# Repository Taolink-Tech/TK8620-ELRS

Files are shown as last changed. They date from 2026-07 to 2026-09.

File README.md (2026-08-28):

# TK8620 ELRS

TK8620 ELRS is an ExpressLRS 3.6.4 firmware port and hardware reference package
for TK8620-based TX and RX modules.

This repository is for people who want to use TK8620 hardware quickly and for
developers who want to evaluate, customize, or integrate TK8620-based radio
modules into their own products.

You can use this repository to:

- buy a TK8620 ELRS module and build firmware for it
- review public hardware design files such as schematics, PCB files, BOMs, and
  manufacturing outputs
- modify the hardware reference design for your own product
- use the ELRS firmware port as a compatibility reference for TK8620 hardware

## Purchase and Contact

- Buy TK8620 ELRS TX/RX modules: [Taobao product page](https://item.taobao.com/item.htm?id=1068476636220)
- Company contact: [+8616621375462](tel:+8616621375462)

## Start Here

| Goal | Start with |
| --- | --- |
| Buy a TK8620 ELRS module | [Taobao product page](https://item.taobao.com/item.htm?id=1068476636220) |
| Choose a module and review purchase notes | [`hardware/PURCHASE.md`](hardware/PURCHASE.md) |
| Build TX/RX firmware | [Build](#build) |
| Interpret the status LED or reset a module | [Status LED and Reset](#status-led-and-reset) |
| Check CRSF, SBUS, and AirPort interfaces | [Serial Interfaces](#serial-interfaces) |
| Bind a TX/RX pair | [Binding](#binding) |
| Switch between RC and AirPort | [RC/AirPort Mode](#rcairport-mode) |
| Flash a TX module | [Flash TX](#flash-tx) |
| Flash an RX module over UART | [Flash RX](#flash-rx) |
| Stage RX firmware for wireless update | [Stage RX Firmware For Wireless Update](#stage-rx-firmware-for-wireless-update) |
| Review hardware files | [`hardware/README.md`](hardware/README.md) |
| Customize your own hardware product | [`hardware/CUSTOMIZATION.md`](hardware/CUSTOMIZATION.md) |

## Supported Hardware

| Hardware | Role | Status | Hardware files | Purchase |
| --- | --- | --- | --- | --- |
| TKB-310 TK8620 ELRS TX Module | TX | Released | [`hardware/boards/tk8620-elrs-tx/`](hardware/boards/tk8620-elrs-tx/) | [`hardware/PURCHASE.md`](hardware/PURCHASE.md) |
| TKM-300 TK8620 ELRS RX Module | RX | Released | [`hardware/boards/tk8620-elrs-rx/`](hardware/boards/tk8620-elrs-rx/) | [`hardware/PURCHASE.md`](hardware/PURCHASE.md) |

Use files from the matching module directory. Do not mix TX and RX schematics,
PCB files, BOMs, placement files, or manufacturing outputs.

## Status LED and Reset

### Status LED

| Module | LED pattern | Meaning |
| --- | --- | --- |
| TX | Steady on | Powered and operating normally. This does not by itself confirm that the RX link is connected. |
| TX | One brief flicker | The short binding transmission window is active. This does not confirm that binding succeeded. |
| RX | Steady on | Connected to the TX module. |
| RX | 500 ms on, 500 ms off | Disconnected and waiting for the TX link. |
| RX | Two short flashes, then a pause | Binding mode. |

The RX patterns apply in both RC and AirPort modes. LED color may vary with the
module hardware revision; use the blink pattern rather than color to identify
the state.

### Reset

`configure.cmd` and `burn.cmd` reset the TX module automatically. When either
tool prompts for an RX manual reset, keep the UART grounds connected, briefly
touch the USB-UART adapter's 3.3 V output to the bottom-side `TP5` reset test
point, and release it immediately. See the module-specific reset notes for the
[`TX`](hardware/boards/tk8620-elrs-tx/README.md#reset) and
[`RX`](hardware/boards/tk8620-elrs-rx/README.md#reset) hardware.

## Serial Interfaces

| Mode and module | Interface | Direction | Serial settings |
| --- | --- | --- | --- |
| RC - TKB-310 TX | CRSF handset | Radio to TX, with telemetry return | Half duplex, 8N1; `400000` default, `420000`, or `921600` baud |
| RC - TKM-300 RX | CRSF | Bidirectional RX/flight-controller UART | Full duplex, normal polarity, 8N1, `420000` baud |
| RC - TKM-300 RX | SBUS | RX to flight controller on the `TX/SBUS` pin | Output only, non-inverted, 8E2, `100000` baud |
| AirPort - TX and RX | Transparent UART | Bidirectional TX/RX byte stream | Full duplex, normal polarity, 8N1; baud selected with `configure.cmd` |

The standard unified TX firmware uses CRSF handset input; SBUS handset input is
not enabled. In RC mode, select CRSF or SBUS for the RX from the receiver Lua
`Serial Protocol` setting. AirPort mode uses the TX and RX UART pins for
transparent serial data instead of RC serial protocols.

## Binding

Set both modules to RC mode. Open the transmitter ELRS Lua menu and select
`Bind`. If the RX is not already in binding mode, power it on three times in
quick succession and leave it powered after the third start. Binding is
complete when the RX status LED becomes steady.

## Repository Contents

- `applications/ELRS_Tx/`: TX application firmware source.
- `applications/ELRS_Rx/`: RX application firmware source.
- `applications/ELRS_Common/`: shared TX/RX application source.
- `hardware/`: hardware reference files, purchase notes, manufacturing outputs,
  and customization guidance.
- `open-sdk/include/`: public TK8620 SDK headers.
- `open-sdk/lib/libtk86xx.a`: TK8620 binary SDK library.
- `firmware/bootloader/`: bootloader image used by `burn.cmd`.
- `tools/`: build, flashing, and packaging tools.
- `VERSION`: repository release version.

This repository does not include prebuilt, linked TX or RX application
firmware. The TX and RX firmware images described below are generated locally
when the user runs the build scripts.

## License Model

This is a mixed-license repository. The ELRS application firmware is derived
from ExpressLRS and remains under GPL-3.0. The TK8620 SDK headers and binary
library are provided under the custom
`LicenseRef-Taolink-TK8620-SDK-Package` license in `LICENSE.sdk.md`.

Hardware reference files under `hardware/` are licensed under the permissive
`CERN-OHL-P-2.0` hardware license unless a specific file states another license.
Customers can modify the hardware for their own products without being required
to publish those hardware changes. Scope and trademark notes are in
[`hardware/LICENSE.md`](hardware/LICENSE.md).

Taolink-owned build, flashing, and packaging tools are provided under the
custom `LicenseRef-Taolink-TK8620-Bundled-Tools` license in `LICENSE.tools.md`.
Third-party components retain their upstream licenses as listed in
`THIRD_PARTY_LICENSES.md`.

The TK8620 bootloader binary is provided under the custom
`LicenseRef-Taolink-TK8620-Bootloader-Binary` license in
`LICENSE.bootloader.md`.

## Requirements

- Windows
- PowerShell
- Nuclei RISC-V GCC `2020.08` / GCC `9.2.0`

Download the verified Windows toolchain:

https://download.nucleisys.com/upload/files/toolchain/gcc/nuclei_riscv_newlibc_prebuilt_win32_2020.08.zip

After extracting the toolchain, add the directory containing
`riscv-nuclei-elf-gcc.exe` to `PATH`, or set `NUCLEI_GCC_BIN` to that directory.

Open a new PowerShell window and run:

```powershell
riscv-nuclei-elf-gcc.exe --version
```

The expected compiler is GCC `9.2.0`.

## Build

Open PowerShell in this repository directory.

Build RX firmware:

```powershell
.\build.cmd rx
```

Build TX firmware:

```powershell
.\build.cmd tx
```

Build both TX and RX:

```powershell
.\build.cmd
```

Clean build output:

```powershell
.\build.cmd clean
```

Build output:

- `build/ELRS_Rx/TK8620_ELRS_RX_P.hex`
- `build/ELRS_Tx/TK8620_ELRS_TX_P.hex`

## RC/AirPort Mode

The same TX and RX firmware supports normal RC operation and AirPort transparent
serial transmission. Flash and bind both devices before switching modes.

Run the interactive configuration tool:

```powershell
.\configure.cmd
```

Select RC, AirPort, or status query, then follow the prompts to reset and
configure each device.
When selecting AirPort, choose one of the supported baud rates: `4800`, `9600`,
`19200`, `38400`, `57600`, `115200`, `230400`, `460800`, or `921600`. The
default is `460800`. Configure both TX and RX to the same mode and baud rate. If
user parameters were erased during flashing, switch to RC and bind the pair
again before using AirPort.

In AirPort mode, connect the computer to the TX module's Type-C serial interface
and connect the external device to the RX module UART TX, RX, and GND pins. Both
serial ports use the selected baud rate with `8 data bits, no parity, 1 stop
bit`, normal polarity, and full duplex. Run `configure.cmd` again to change the
AirPort baud rate on both devices.

The selected UART baud rate controls the local serial ports; it does not change
the fixed AirPort RF rate or guarantee continuous over-the-air throughput at
that baud. Higher rates are intended for burst traffic. Applications that send
continuous data must stay within the available RF throughput and handle
overflow or loss.

AirPort carries a byte stream, not application packet boundaries. It does not
acknowledge or retransmit lost RF packets. Applications that require complete
messages must add their own framing, length, sequence, checksum, and retry
logic. Restore RC operation by running `configure.cmd` and setting both modules
to RC.

## Flash TX

Build TX firmware first:

```powershell
.\build.cmd tx
```

Connect the TX module UART through a USB-to-UART adapter, then run:

```powershell
.\burn.cmd tx
```

The script lists detected COM ports and asks you to select the target port.
TX user settings are preserved by default. Add `-Erase` only when you
intentionally want to reset them.

## Flash RX

Use this method when you can connect the RX module UART directly to a
USB-to-UART adapter.

Build the RX firmware first:

```powershell
.\build.cmd rx
```

Connect the RX module UART through a USB-to-UART adapter, then run:

```powershell
.\burn.cmd rx
```

The script lists detected COM ports and asks you to select the RX module port.
This command flashes the RX module over its UART connection.
RX user settings and binding are preserved by default. Add `-Erase` only when
you intentionally want to reset them; the RX must then be bound again.

## Stage RX Firmware For Wireless Update

Use this method when the RX module will be updated wirelessly from the TX
module. In this flow, the computer connects to the TX module UART. The RX module
does not need to be connected to the computer by UART.

Build the RX firmware first:

```powershell
.\build.cmd rx
```

Connect the TX module UART through a USB-to-UART adapter, then stage the RX
firmware image into TX flash:

```powershell
.\burn.cmd rx-stash
```

The RX image path is fixed:

```text
build/ELRS_Rx/TK8620_ELRS_RX_P.hex
```

After staging, keep the RX module within RF range of the TX module. Start the RX
wireless update from the TX firmware by using one of these methods:

- Send this hexadecimal command to the TX module serial port:

  ```text
  EE062DEEEF0A0150
  ```

- Open the transmitter Lua menu and start the RX wireless update from the menu.

After the TX module enters wireless update mode, reset the RX module using the
[`TP5` procedure](hardware/boards/tk8620-elrs-rx/README.md#reset). Wait for the
wireless update to complete.

## Licenses

- `LICENSE.md`: GPL-3.0 license for ELRS-derived application firmware.
- `hardware/LICENSE.md`: CERN-OHL-P-2.0 license scope for hardware files.
- `LICENSE.sdk.md`: custom TK8620 SDK package license.
- `LICENSE.bootloader.md`: custom TK8620 bootloader binary license.
- `LICENSE.tools.md`: custom bundled Taolink tools license.
- `THIRD_PARTY_LICENSES.md`: third-party notices.

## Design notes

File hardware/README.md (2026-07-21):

# TK8620 ELRS Hardware

This directory is the user-facing entry point for TK8620 ELRS hardware
reference files. It is written for both first-time users and experienced
hardware developers.

You can use these files to identify a module, review the design, manufacture a
prototype, or adapt the reference hardware for your own product.

## Start Here

| Goal | Start with |
| --- | --- |
| Buy a module and use the open firmware | [`PURCHASE.md`](PURCHASE.md) |
| Find hardware files for a module | [`boards/`](boards/) |
| Customize hardware for your own product | [`CUSTOMIZATION.md`](CUSTOMIZATION.md) |
| Check hardware license status | [`LICENSE.md`](LICENSE.md) |

## Module File Rule

Hardware files are grouped by module. TX and RX modules are separate boards, so
use files from the matching module directory.

Do not mix schematics, PCB files, BOMs, placement files, or manufacturing
outputs from TX and RX modules. Mixing files can cause pinout
mismatches, assembly errors, or firmware incompatibility.

## Directory Layout

- `boards/`: module-specific TX and RX hardware files.
- `PURCHASE.md`: module purchase and selection notes.
- `CUSTOMIZATION.md`: guidance for adapting the reference hardware.
- `LICENSE.md`: CERN-OHL-P-2.0 license scope for hardware files.

## Current Module File Set

The released module directories include:

- editable EDA source project
- available schematic exports
- Gerber, drill, BOM, and related manufacturing outputs
- firmware compatibility notes for that module

## Relationship With Firmware

This repository can build TX and RX firmware:

- TX output: `build/ELRS_Tx/TK8620_ELRS_TX_P.hex`
- RX output: `build/ELRS_Rx/TK8620_ELRS_RX_P.hex`

Before buying or building hardware, confirm that the module supports the TX or
RX role you need. Also check the interface, power, antenna, and RF band
information in the module README.

## Custom Products

The hardware reference files are licensed under `CERN-OHL-P-2.0` unless noted
otherwise. Customers may modify the reference design and use those modifications
in their own products without being required by this hardware documentation to
publish their hardware changes. Feedback and upstream contributions are welcome,
but optional.

Firmware based on ExpressLRS is separate and remains subject to its GPL-3.0
license.

## RF And Regulatory Notice

ELRS modules involve RF transmission and reception. Before buying, modifying,
manufacturing, or using hardware, confirm that your use case complies with local
RF regulations, frequency requirements, power limits, antenna requirements, and
safety requirements.

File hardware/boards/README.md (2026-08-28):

# Hardware Boards

This directory organizes TK8620 ELRS hardware reference files by module.

TX and RX modules are separate boards. Each module directory contains the EDA
source, available schematic exports, manufacturing outputs, and firmware
compatibility information for that module.

## Boards

| Module | Description | Files |
| --- | --- | --- |
| TKB-310 TK8620 ELRS TX Module | TX transmitter module hardware | [`tk8620-elrs-tx/`](tk8620-elrs-tx/) |
| TKM-300 TK8620 ELRS RX Module | RX receiver module hardware | [`tk8620-elrs-rx/`](tk8620-elrs-rx/) |

## Usage

- New users can start with [`../PURCHASE.md`](../PURCHASE.md) to identify the
  module to buy.
- Firmware developers can open a module directory to check firmware
  compatibility and interfaces.
- Hardware developers can use a module directory as the starting point for a
  custom product.

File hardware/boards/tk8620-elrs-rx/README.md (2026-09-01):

# TKM-300 TK8620 ELRS RX Module

This directory contains the public hardware files for the TK8620 ELRS RX
module. TX and RX modules are separate boards, so use this directory only for
the RX receiver module.

## Module Information

| Item | Value |
| --- | --- |
| Product model | TKM-300 |
| Module type | TK8620 ELRS RX Module |
| Supported role | RX receiver module |
| Operating modes | RC receiver and AirPort transparent serial |
| RF band | 905.3-925.3 MHz (`SAW_915` firmware domain) |
| FHSS frequencies | 40; approximately 512.82 kHz spacing; approximately 916.069 MHz sync frequency |
| RF packet rates | 25, 50, 100, 200, and 250 Hz |
| RC channels | Up to 16 |
| Telemetry power setting | Configured maximum 100 mW (20 dBm) |
| Firmware sensitivity reference | -123 dBm at 25 Hz; -120 dBm at 50 Hz; -117 dBm at 100 Hz; -114 dBm at 200 Hz; -112 dBm at 250 Hz |
| RC serial protocols | CRSF or SBUS, selectable from the receiver Lua `Serial Protocol` setting |
| CRSF serial | Bidirectional, full duplex, normal polarity, 8N1, 420000 baud |
| SBUS serial | Output only on `TX/SBUS`, non-inverted, 8E2, 100000 baud |
| AirPort serial | Bidirectional TX/RX UART, full duplex, normal polarity, 8N1; selectable baud, 460800 default |
| Antenna connector | IPEX |
| Input voltage | 5 V nominal |
| Dimensions | 11 x 17 mm |
| UART pins | GND, 5V, TX/SBUS, RX |
| Firmware update | Local UART or wireless update from the TX module |
| EDA tool | Altium Designer 16 |
| Firmware output | `build/ELRS_Rx/TK8620_ELRS_RX_P.hex` |
| Release status | Released |
| Purchase page | [`../../PURCHASE.md`](../../PURCHASE.md) |

## Files

- [`eda/`](eda/): editable Altium Designer source project and EDA notes.
- [`fabrication/`](fabrication/): manufacturing outputs.
- [`images/`](images/): board photos used by this guide.

## Firmware Use

Build the RX firmware from the repository root:

```powershell
.\build.cmd rx
```

Flash the RX module by following [`Flash RX`](../../../README.md#flash-rx), or
stage it for wireless update by following
[`Stage RX Firmware For Wireless Update`](../../../README.md#stage-rx-firmware-for-wireless-update).
AirPort baud-rate choices and mode switching are documented under
[`RC/AirPort Mode`](../../../README.md#rcairport-mode).

## RC Serial Connection

For CRSF, connect module `TX/SBUS` to the flight-controller RX pin and module
`RX` to the flight-controller TX pin. Also connect 5V and GND, then select
`CRSF` in the receiver Lua `Serial Protocol` setting.

For SBUS, connect module `TX/SBUS` to the flight-controller SBUS input and
connect 5V and GND. Select `SBUS` in the receiver Lua `Serial Protocol` setting;
the module `RX` pin is not used in SBUS mode.

## Reset

The RX reset point is `TP5` on the bottom side of the module. It is marked
`TP5` on the bottom silkscreen.

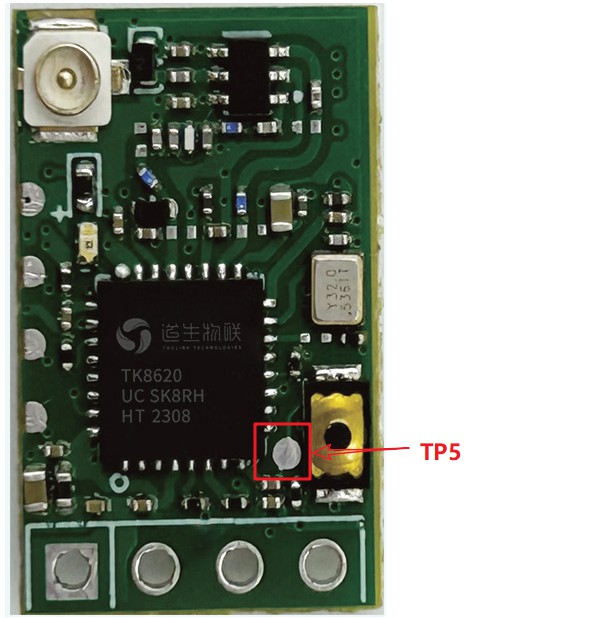
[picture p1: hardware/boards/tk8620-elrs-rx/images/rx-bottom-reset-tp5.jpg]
RX module bottom side with the TP5 reset pad marked


When `configure.cmd` or `burn.cmd` displays the manual-reset prompt, briefly
touch the USB-UART adapter's 3.3 V output to `TP5`, then remove it immediately.
Keep the USB-UART adapter and RX module grounds connected during this step. Do
not leave `TP5` connected to 3.3 V.

## Custom Hardware Notes

If you use this module as the starting point for your own product, keep this
module file set together and read [`../../CUSTOMIZATION.md`](../../CUSTOMIZATION.md)
before modifying the design.

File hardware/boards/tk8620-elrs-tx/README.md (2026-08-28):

# TKB-310 TK8620 ELRS TX Module

This directory contains the public hardware files for the TK8620 ELRS TX
module. TX and RX modules are separate boards, so use this directory only for
the TX transmitter module.

## Module Information

| Item | Value |
| --- | --- |
| Product model | TKB-310 |
| Module type | TK8620 ELRS TX Module |
| Supported role | TX transmitter module |
| Operating modes | RC transmitter and AirPort transparent serial |
| RF band | 905.3-925.3 MHz (`SAW_915` firmware domain) |
| FHSS frequencies | 40; approximately 512.82 kHz spacing; approximately 916.069 MHz sync frequency |
| RF packet rates | 25, 50, 100, 200, and 250 Hz |
| RC channels | Up to 16 |
| Firmware power settings | 50, 100, 250, 500, or 1000 mW; configured maximum 1000 mW (30 dBm) |
| Dynamic power | Supported in RC mode |
| Radio control input | CRSF handset input; SBUS handset input is not enabled in the standard firmware |
| CRSF serial | Half duplex, 8N1; 400000 baud default, selectable 420000 or 921600 |
| AirPort serial | Full duplex, normal polarity, 8N1; selectable baud, 460800 default |
| Antenna connector | SMA |
| Input voltage | 7-12.6 V |
| Radio module interface | Nano external-module interface |
| Onboard USB-UART | Type-C connector for configuration, flashing, and AirPort serial |
| EDA tool | Cadence 16.6 |
| Firmware output | `build/ELRS_Tx/TK8620_ELRS_TX_P.hex` |
| Release status | Released |
| Purchase page | [`../../PURCHASE.md`](../../PURCHASE.md) |

## Files

- [`eda/`](eda/): editable Cadence source project and EDA notes.
- [`schematics/`](schematics/): exported schematic review files.
- [`fabrication/`](fabrication/): manufacturing outputs.

## Firmware Use

Build the TX firmware from the repository root:

```powershell
.\build.cmd tx
```

Flash the TX module by following [`Flash TX`](../../../README.md#flash-tx).
AirPort baud-rate choices and mode switching are documented under
[`RC/AirPort Mode`](../../../README.md#rcairport-mode).

## Reset

`configure.cmd` and `burn.cmd` reset the TX module automatically through the
onboard USB-UART interface, so no manual reset is normally required.

## Custom Hardware Notes

If you use this module as the starting point for your own product, keep this
module file set together and read [`../../CUSTOMIZATION.md`](../../CUSTOMIZATION.md)
before modifying the design.

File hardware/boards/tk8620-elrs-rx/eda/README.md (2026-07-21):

# EDA Source Project

This directory contains the editable hardware source project for this hardware
module. Hardware developers can use it to review, modify, and regenerate
schematics, PCB files, BOMs, placement files, and manufacturing outputs.

Available generated PDFs, Gerbers, and BOMs are stored in sibling directories
so users can review or evaluate production without opening the EDA project.

## Project

- [`altium/`](altium/): Altium Designer source project.

## Notes

- Confirm that you are using the complete TX or RX module file set before
  modifying the project.
- After modifying the source project, regenerate affected manufacturing files
  in [`../fabrication/`](../fabrication/).

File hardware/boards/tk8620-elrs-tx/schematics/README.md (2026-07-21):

# Schematics

This directory contains exported schematics for this hardware module. Use them
to review circuit connections, interfaces, power paths, and key components.

Schematic exports should be generated from the matching [`../eda/`](../eda/)
source project. When reviewing or modifying hardware, cross-check the exported
schematic with the source project.

## Files

- [`ELRS-TX-MODULE-V13-20260608.pdf`](ELRS-TX-MODULE-V13-20260608.pdf):
  exported schematic PDF.

## Typical Uses

- Confirm module interfaces, power, UART, buttons, LEDs, and RF path.
- Check hardware connections before changing firmware pins or peripherals.
- Decide which circuits can be reused and which need validation in a custom
  product.

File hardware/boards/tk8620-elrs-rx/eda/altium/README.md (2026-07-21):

# Altium Designer Project

This directory contains the Altium Designer source project for this hardware
module. Open the project in a compatible Altium Designer version to review or
modify the schematic and PCB.

## Design Source

- Altium Designer 16
- [`ELRS-RX-MODULE-V11-20260127.PrjPcb`](ELRS-RX-MODULE-V11-20260127.PrjPcb):
  project file.
- [`01_SOC.SchDoc`](01_SOC.SchDoc), [`02_RF.SchDoc`](02_RF.SchDoc),
  [`03_Power.SchDoc`](03_Power.SchDoc), [`04_UART.SchDoc`](04_UART.SchDoc),
  and [`05_Notes.SchDoc`](05_Notes.SchDoc): schematic source sheets.
- [`ELRS-RX-MODULE-V11-20260204.PcbDoc`](ELRS-RX-MODULE-V11-20260204.PcbDoc):
  PCB layout source.
- [`ELRS-RX-MODULE-V11-20260204.PcbLib`](ELRS-RX-MODULE-V11-20260204.PcbLib):
  PCB footprint library.
- [`ELRS-RX-MODULE-V11-20260127.OutJob`](ELRS-RX-MODULE-V11-20260127.OutJob):
  output job configuration.
- [`ELRS-RX-MODULE-V11-20260127.PrjPcbStructure`](ELRS-RX-MODULE-V11-20260127.PrjPcbStructure):
  project hierarchy metadata.

## Notes

- Manufacturing files are not stored here. Exported manufacturing files are in
  [`../../fabrication/`](../../fabrication/).
- The project, PCB, and manufacturing output filenames contain different dates.
  Keep this complete file set together when reviewing the released design.
- After modifying the project, update the exported schematic and manufacturing
  files.

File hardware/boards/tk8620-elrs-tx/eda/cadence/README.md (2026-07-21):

# Cadence Project

This directory contains the Cadence source project for this hardware module.
Open the project in the matching Cadence toolchain to review or modify the
schematic and PCB.

## Design Source

- Cadence 16.6
- [`ELRS-TX-MODULE-V13-20260608.DSN`](ELRS-TX-MODULE-V13-20260608.DSN):
  OrCAD Capture schematic source.
- [`ELRS-TX-MODULE-V13-20260610.brd`](ELRS-TX-MODULE-V13-20260610.brd):
  Allegro PCB layout source.

## Notes

- Manufacturing files are not stored here. Exported manufacturing files are in
  [`../../fabrication/`](../../fabrication/).
- After modifying the project, update the exported schematic and manufacturing
  files.

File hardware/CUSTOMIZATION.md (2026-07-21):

# Customize Your Own Product

This repository supports two different customization paths:

- ELRS-derived firmware customization
- TK8620 hardware reference customization

The license obligations are different. ELRS-derived application firmware remains
under GPL-3.0. Hardware reference files are licensed under `CERN-OHL-P-2.0`
unless a specific file states another license, so customers can adapt the
hardware for their own products without being required to publish their hardware
changes. Feedback is welcome, but optional.

## Recommended Workflow

1. Select the reference module closest to your product, for example
   [`boards/tk8620-elrs-tx/`](boards/tk8620-elrs-tx/) or
   [`boards/tk8620-elrs-rx/`](boards/tk8620-elrs-rx/).
2. Record the repository version, module type, and source commit you started
   from.
3. Define your change goal, such as connector changes, antenna changes, power
   input changes, size changes, enclosure integration, or firmware behavior.
4. Modify the EDA source project and regenerate the schematic, BOM, placement
   files, and manufacturing outputs that are affected.
5. Update firmware pin, peripheral, power, or device configuration when the
   hardware change requires it.
6. Build TX/RX firmware and validate it on prototype hardware.
7. Complete power, RF, temperature, reliability, and regulatory checks for your
   product.
8. Keep an internal change record for your product. If you want to contribute a
   fix or improvement upstream, open an issue or pull request.

## Keep Module Files Together

Each module directory is a complete file set. When you customize hardware, start
from one module directory and keep its schematic, PCB source, BOM, placement,
and manufacturing files together.

Create a separate product version or board directory for your product if your
changes affect:

- schematic connections or key component choices
- PCB stackup, RF path, antenna interface, or impedance control
- power tree, input voltage range, or protection circuit
- connector definitions, pin assignments, or mechanical outline
- mounting holes, board outline, height limits, or thermal design
- production, test, or calibration flow

## Files To Check When You Customize

| Change type | Check these files |
| --- | --- |
| Firmware behavior or protocol change | `applications/ELRS_Tx/`, `applications/ELRS_Rx/`, `applications/ELRS_Common/` |
| Pin or peripheral change | firmware configuration, schematic, PCB, test notes |
| Antenna or RF path change | schematic, PCB source, RF test record, regulatory requirements |
| Power change | schematic, BOM, PCB, thermal design, power test record |
| Mechanical or mounting change | PCB source, product-specific CAD, board measurements, board images, assembly notes |
| Production data change | `fabrication/`, BOM, placement files, Gerber, drill files |

## Sharing Changes Is Optional

You are encouraged, but not required by the hardware documentation, to share
hardware improvements with Taolink or the community. Useful feedback includes:

- bug reports
- unclear documentation
- manufacturing issues
- RF or power validation findings
- improvements that you are willing to contribute back

If you distribute modified GPL firmware, the GPL firmware obligations still
apply to that firmware. This is separate from permissive hardware customization.

## Before Production

The hardware files in this repository help you start a design, but they do not
replace product validation. Before using a custom hardware product in
production, complete your own checks for:

- hardware and firmware compatibility
- schematic and PCB review
- BOM availability and approved alternates
- manufacturing test procedure
- RF calibration, RF performance, and local regulatory compliance
- power safety, thermal behavior, and reliability

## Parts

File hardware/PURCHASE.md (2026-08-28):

# Buy TK8620 ELRS Hardware Modules

This page helps you choose and buy TK8620 ELRS hardware modules that can be used
with firmware built from this repository.

If you only want to use the firmware and do not want to build or modify PCB
hardware, start with the ready-made module purchase page below. Select the TX
or RX variant on the product page, then build and flash the matching firmware.

## Before You Buy

Check these items before buying:

- whether you need the TX variant, the RX variant, or both variants
- whether the module type is documented in this repository
- whether the RF band, antenna connector, and input voltage match your use case
- whether you plan to build and flash firmware from this repository
- whether your region allows the selected frequency, power, and antenna setup

## Module Purchase

| Product | Variants | Status | Purchase link | Hardware files |
| --- | --- | --- | --- | --- |
| TK8620 ELRS Module | TKB-310 TX and TKM-300 RX; order both for a matched pair | Released | [Taobao product page](https://item.taobao.com/item.htm?ft=t&id=1068476636220&spm=a21dvs.23580594.0.0.4fee2c1bPYE3AY) | [`TX`](boards/tk8620-elrs-tx/) / [`RX`](boards/tk8620-elrs-rx/) |

## After You Receive A Module

1. Check your selected product variant, package label, or purchase record to
   confirm whether the module is TX or RX.
2. Open the matching module README under [`boards/`](boards/).
3. Install the toolchain and build TX or RX firmware from the repository root.
4. Connect UART, power, and antenna according to the module notes.
5. Flash or update the firmware.

## Build Or Modify Your Own Hardware

If you do not buy a ready-made module and instead want to build or modify
hardware from the reference files, read [`CUSTOMIZATION.md`](CUSTOMIZATION.md)
before using the EDA and manufacturing files for a module.

Custom hardware requires your own manufacturing checks, RF validation, power
safety validation, and regulatory review.

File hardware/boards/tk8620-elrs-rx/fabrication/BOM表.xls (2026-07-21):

客户BOM清单
Comment | Description | Designator | Footprint | LibRef | Quantity | 顶层位号 | 顶层数 | 顶层贴装 | 底层位号 | 底层数 | 底层贴装 | 元件编号 | X-ray检查 | 贴装总数量 | 焊点总数量 | 焊点费小计 | 元件名称 | 原厂型号 | 封装规格 | 最小起订数量 | 损耗数量 | 元器件来源 | 工厂元件单价 | 工厂元件小计 | 换料费
8.2nH |  | L9 | 0201 | INDUCTOR_Dup2 | 1 | L9 | 1 | 已贴装 |  | 0 | 已贴装 | C370186 | 不需要 | 30 | 60 | 0.6000 | 8.2nH ±5% | SDCL0603Q8N2JT02B03 | 0201 | 20 | 10 | 商城现货 | 0.0306 | 1.224 | 8.00
1.5pF | CeramicCapacitor,22uF,6.3V,+/-20%,X5R,0603,Samsung | C42,C79 | 0201 | CeramicCapacitor | 2 | C42 | 1 | 已贴装 | C79 | 1 | 已贴装 | C161414 | 不需要 | 60 | 120 | 1.2000 | ±0.1pF 1.5pF 50V | GRM0335C1H1R5BA01D | 0201 | 20 | 20 | 商城现货 | 0.0173 | 1.384 | 8.00
4.3pF | CeramicCapacitor,22uF,6.3V,+/-20%,X5R,0603,Samsung | C41 | 0201 | CeramicCapacitor | 1 | C41 | 1 | 已贴装 |  | 0 | 已贴装 | C285053 | 不需要 | 30 | 60 | 0.6000 | ±0.25pF 4.3pF 50V | 0201CG4R3C500NT | 0201 | 20 | 10 | 商城现货 | 0.0097 | 0.388 | 8.00
4.7nH |  | L3 | 0201 | INDUCTOR_Dup2 | 1 | L3 | 1 | 已贴装 |  | 0 | 已贴装 | C162621 | 不需要 | 30 | 60 | 0.6000 | 4.7nH ±5% | LQP03TN4N7J02D | 0201 | 20 | 10 | 商城现货 | 0.0425 | 1.7 | 8.00
100nF/10V | CeramicCapacitor,100nF,50V,+/-10%,X7R,0402,Fenghua,[NoValue],CeramicCapacitor,22uF,6.3V,+/-20%,X5R,0603,Samsung | C3,C6,C7,C10,C11,C12,C14,C26,C28,C35,C36,C183,C191,C193 | 0201 | CeramicCapacitor_14,CAP_NP,CeramicCapacitor | 14 | C6, C7, C12, C14, C26, C28, C35, C193 | 8 | 已贴装 | C3, C10, C11, C36, C183, C191 | 6 | 已贴装 | C76939 | 不需要 | 480 | 960 | 9.6000 | 100nF ±10% 25V | GRM033R61E104KE14D | 0201 | 20 | 24 | 商城现货 | 0.0221 | 11.1384 | 8.00
100nF16V | CeramicCapacitor,22uF,6.3V,+/-20%,X5R,0603,Samsung | C76,C80 | 0201 | CeramicCapacitor | 2 |  | 0 | 已贴装 | C76, C80 | 2 | 已贴装 | C76939 | 不需要
7.5nH |  | L8,L17 | 0201 | INDUCTOR_Dup2,INDUCTOR | 2 | L8 | 1 | 已贴装 | L17 | 1 | 已贴装 | C2044085 | 不需要 | 60 | 120 | 1.2000 | 7.5nH ±3% | LQP03HQ7N5H02D | 0201 | 5 | 8 | 商城现货 | 0.1480 | 10.064 | 8.00
4.7uH |  | L23 | R0603 | INDUCTOR_Dup1 | 1 |  | 0 | 已贴装 | L23 | 1 | 已贴装 | C114862 | 不需要 | 30 | 60 | 0.6000 | 4.7uH ±20% | LQM18PN4R7MFRL | 0603 | 5 | 4 | 商城现货 | 0.3530 | 12.002 | 8.00
2.2UH0.75A |  | L22 | C0603 | INDUCTOR_Dup2 | 1 | L22 | 1 | 已贴装 |  | 0 | 已贴装 | C394950 | 不需要 | 30 | 60 | 0.6000 | 2.2uH ±20% | CMH160808B2R2MT | 0603 | 20 | 8 | 商城现货 | 0.1700 | 6.46 | 8.00
MS2630 |  | U9 | SOT23-6 | MS2630 | 1 |  | 0 | 已贴装 | U9 | 1 | 已贴装 | C9900189707 | 不需要 | 30 | 180 | 1.8000 | 【邮寄专用】MS2630 | MS2630 | SOT23-6 | 5 | 4 | 邮寄 | 1 | 1 | 8.00
56pF/6.3V | CeramicCapacitor,22uF,6.3V,+/-20%,X5R,0603,Samsung | C23,C43,C44 | 0201 | CeramicCapacitor | 3 | C23, C43, C44 | 3 | 已贴装 |  | 0 | 已贴装 | C115561 | 不需要 | 90 | 180 | 1.8000 | 56pF ±5% 50V | C0201C0G560J500NTA | 0201 | 20 | 10 | 商城现货 | 0.0081 | 0.81 | 8.00
49.9k/1% | ThickFilmResistor,0R,+/-5%,1/16W,-55°C~155°C,SMD,0402,Fenghua | R21 | 0201 | Resister | 1 |  | 0 | 已贴装 | R21 | 1 | 已贴装 | C473512 | 不需要 | 30 | 60 | 0.6000 | 49.9kΩ ±1% 50mW 厚膜电阻 | 0201WMF4992TEE | 0201 | 20 | 10 | 商城现货 | 0.0058 | 0.232 | 8.00
10uF10V |  | C29,C30,C185,C188 | 0402C_MIN | CAPACITORNON-POL,CAP_NP | 4 | C185 | 1 | 已贴装 | C29, C30, C188 | 3 | 已贴装 | C315248 | 不需要 | 120 | 240 | 2.4000 | 10uF ±20% 10V | CL05A106MP5NUNC | 0402 | 20 | 24 | 商城现货 | 0.0569 | 8.1936 | 8.00
MT2492 |  | U4 | SOT23-6 | MT2492 | 1 |  | 0 | 已贴装 | U4 | 1 | 已贴装 | C89358 | 不需要 | 30 | 180 | 1.8000 | 降压型 2A 4.5V~16V | MT2492 | SOT-23-6 | 5 | 4 | 商城现货 | 0.2840 | 9.656 | 8.00
22nF |  | C22 | 0201 | CAPACITORNON-POL | 1 |  | 0 | 已贴装 | C22 | 1 | 已贴装 | C5142560 | 不需要 | 30 | 60 | 0.6000 | 22nF ±10% 25V | TCC0201X5R223K250ZT | 0201 | 20 | 10 | 商城现货 | 0.0048 | 0.192 | 8.00
RCLAMP0521P.TCT-MS |  | D2 | TVS-0402 | TVS | 1 | D2 | 1 | 已贴装 |  | 0 | 已贴装 | C3029033 | 不需要 | 30 | 60 | 0.6000 | 丝印N 双向TVS 5V截止 峰值脉冲电流：4A | RCLAMP0521P.TCT-MS | 0402 | 20 | 8 | 商城现货 | 0.1130 | 4.294 | 8.00
LED_Green |  | D6 | LED0402 | MFOE1101_0 | 1 | D6 | 1 | 已贴装 |  | 0 | 已贴装 | C364551 | 不需要 | 30 | 60 | 0.6000 | 普绿/黄绿 光强4.5mcd;28mcd | LTST-C281KGKT-5A | 0402 | 5 | 4 | 商城现货 | 0.3410 | 11.594 | 8.00
TK8620 |  | U1 | QFN32_8620 | K2201A_3 | 1 | U1 | 1 | 已贴装 |  | 0 | 已贴装 | C9900047938 | 不需要 | 30 | 990 | 9.9000 | TK8620B | TK8620B | QFN32_5X5 | 0 | 0 | 邮寄 | 0.0000 | 0 | 8.00
1K |  | R14 | 0201 | R_0 | 1 | R14 | 1 | 已贴装 |  | 0 | 已贴装 | C138165 | 不需要 | 30 | 60 | 0.6000 | 厚膜电阻 1kΩ ±1% 50mW | RC0201FR-071KL | 0201 | 20 | 12 | 商城现货 | 0.0063 | 0.2646 | 8.00
22 |  | R77,R80 | 0201 | RES | 2 | R77, R80 | 2 | 已贴装 |  | 0 | 已贴装 | C270355 | 不需要 | 60 | 120 | 1.2000 | 22Ω ±1% 50mW 厚膜电阻 | 0201WMF220JTEE | 0201 | 20 | 10 | 商城现货 | 0.0053 | 0.371 | 8.00
120_100MHz | FERRITECHIP120OHM500MA0402 | B1,B7 | L0402 | 1212_BEAD_0 | 2 | B1 | 1 | 已贴装 | B7 | 1 | 已贴装 | C76891 | 不需要 | 60 | 120 | 1.2000 | 单路 0402磁珠 阻抗120Ω@100MHz | BLM15PD121SN1D | 0402 | 20 | 24 | 商城现货 | 0.0336 | 2.8224 | 8.00
6.8pF | CeramicCapacitor,22uF,6.3V,+/-20%,X5R,0603,Samsung | C40 | 0201 | CeramicCapacitor | 1 | C40 | 1 | 已贴装 |  | 0 | 已贴装 | C85916 | 不需要 | 30 | 60 | 0.6000 | ±0.25pF 6.8pF 50V | GRM0335C1H6R8CA01D | 0201 | 20 | 10 | 商城现货 | 0.0117 | 0.468 | 8.00
1uF/10V | CeramicCapacitor,4.7uF10V0402,SUMSUNG | C2,C192 | 0201 | CeramicCapacitor | 2 | C2, C192 | 2 | 已贴装 |  | 0 | 已贴装 | C6119758 | 不需要 | 60 | 120 | 1.2000 | 1uF ±20% 10V | CGA0201X5R105M100ET | 0201 | 20 | 10 | 商城现货 | 0.0179 | 1.253 | 8.00
IPEX-1 |  | J1 | IPEX-1 | IPEX-1 | 1 | J1 | 1 | 已贴装 |  | 0 | 已贴装 | C2987682 | 不需要 | 30 | 120 | 1.2000 | 内针 IPEX | IPEX-1 | SMD | 5 | 4 | 商城现货 | 0.4880 | 16.592 | 8.00
1KR_100MHz/200mA | FERRITECHIP120OHM500MA0402,[NoValue],ThickFilmResistor,0R,+/-5%,1/16W,-55°C~155°C,SMD,0402,Fenghua | B4,B5,B6,B8,R20 | 0201 | 1212_BEAD_0,INDUCTOR_Dup1,Resister | 5 | B5, B6, R20 | 3 | 已贴装 | B4, B8 | 2 | 已贴装 | C88948 | 不需要 | 150 | 300 | 3.0000 | 单路 0201磁珠 阻抗1kΩ@100MHz | BLM03AG102SN1D | 0201 | 20 | 20 | 商城现货 | 0.0376 | 6.392 | 8.00
6.2nH |  | L18 | 0201 | INDUCTOR | 1 |  | 0 | 已贴装 | L18 | 1 | 已贴装 | C162627 | 不需要 | 30 | 60 | 0.6000 | 6.2nH ±3% | LQP03TN6N2H02D | 0201 | 20 | 10 | 商城现货 | 0.0261 | 1.044 | 8.00
0R | ThickFilmResistor,0R,+/-5%,1/16W,-55°C~155°C,SMD,0402,Fenghua | R83 | 0201 | Resister | 1 |  | 0 | 已贴装 | R83 | 1 | 已贴装 | C473473 | 不需要 | 30 | 60 | 0.6000 | 0Ω ±1% 50mW 厚膜电阻 【标准型专用】 | 0201WMF0000TEE | 0201 | 20 | 12 | 商城现货 | 0.0050 | 0.21 | 8.00
220nHLQW15CNR22J10D |  | L2 | L0402 | INDUCTOR_Dup2 | 1 | L2 | 1 | 已贴装 |  | 0 | 已贴装 | C162549 | 不需要 | 30 | 60 | 0.6000 | 220nH ±5% | LQG15HSR22J02D | 0402 | 20 | 10 | 商城现货 | 0.0514 | 2.056 | 8.00
X1E0002510059 |  | X1 | SMD2016-4P | Crystal_32M | 1 | X1 | 1 | 已贴装 |  | 0 | 已贴装 | C48332759 | 不需要 | 30 | 120 | 1.2000 | YSO510TP 32MHZ 1.8V ±1.5PPM -30~85℃ (±0.5PPM) Clipped Sine Wave | OW7EL89CANUXK7YLC-32M | SMD2016-4P | 2 | 0 | 商城现货 | 2.3750 | 71.25 | 8.00
2.2pF | CeramicCapacitor,22uF,6.3V,+/-20%,X5R,0603,Samsung | C78 | 0201 | CeramicCapacitor | 1 |  | 0 | 已贴装 | C78 | 1 | 已贴装 | C3881041 | 不需要 | 30 | 60 | 0.6000 | ±0.05pF 2.2pF 25V | GRM0335C1E2R2WA01D | 0201 | 20 | 10 | 商城现货 | 0.0565 | 2.26 | 8.00
12nH |  | L6 | 0201 | INDUCTOR_Dup2 | 1 | L6 | 1 | 已贴装 |  | 0 | 已贴装 | C162597 | 不需要 | 30 | 60 | 0.6000 | 12nH ±3% | LQP03TN12NH02D | 0201 | 20 | 10 | 商城现货 | 0.0346 | 1.384 | 8.00
22uF/16V | CeramicCapacitor,10uF,+/-20%,X6S,16V,SMD,0603,CeramicCapacitor,100nF,50V,+/-10%,X7R,0402,Fenghua | C1,C5 | C0402 | CeramicCapacitor,CeramicCapacitor_14 | 2 | C1, C5 | 2 | 已贴装 |  | 0 | 已贴装 | C415703 | 不需要 | 60 | 120 | 1.2000 | 22uF ±20% 6.3V | GRM155R60J226ME11D | 0402 | 5 | 4 | 商城现货 | 0.2340 | 14.976 | 8.00
24K |  | R25 | 0201 | R | 1 |  | 0 | 已贴装 | R25 | 1 | 已贴装 | C273277 | 不需要 | 30 | 60 | 0.6000 | 厚膜电阻 24kΩ ±1% 50mW | RC0201FR-0724KL | 0201 | 20 | 10 | 商城现货 | 0.0067 | 0.268 | 8.00
AS179-92 |  | U2 | SC70-6 | AS179-92 | 1 | U2 | 1 | 已贴装 |  | 0 | 已贴装 | C83422 | 不需要 | 30 | 180 | 1.8000 | 20MHz至4.0GHzGaAsSPDT射频开关 | AS179-92LF | SC-70-6(SOT-363) | 5 | 0 | 商城现货 | 6.3500 | 190.5 | 8.00
100K/1% | ThickFilmResistor,0R,+/-5%,1/16W,-55°C~155°C,SMD,0402,Fenghua | R4,R11 | 0201 | Resister | 2 | R4 | 1 | 已贴装 | R11 | 1 | 已贴装 | C270364 | 不需要 | 90 | 180 | 1.8000 | 100kΩ ±1% 50mW 厚膜电阻 【标准型专用】 | 0201WMF1003TEE | 0201 | 20 | 24 | 商城现货 | 0.0050 | 0.57 | 8.00
100K |  | R24 | 0201 | R | 1 |  | 0 | 已贴装 | R24 | 1 | 已贴装 | C270364 | 不需要
750R | ThickFilmResistor,0R,+/-5%,1/16W,-55°C~155°C,SMD,0402,Fenghua | R37 | 0201 | Resister | 1 |  | 0 | 已贴装 | R37 | 1 | 已贴装 | C2936643 | 不需要 | 30 | 60 | 0.6000 | 厚膜电阻 750Ω ±1% 50mW | RHC-01W7500FT | 0201 | 20 | 10 | 商城现货 | 0.0131 | 0.524 | 8.00
8pF/6.3V | CeramicCapacitor,22uF,6.3V,+/-20%,X5R,0603,Samsung | C19 | 0201 | CeramicCapacitor | 1 | C19 | 1 | 已贴装 |  | 0 | 已贴装 | C237417 | 不需要 | 30 | 60 | 0.6000 | ±0.1pF 8pF 50V | GRM0335C1H8R0BA01D | 0201 | 20 | 10 | 商城现货 | 0.0172 | 0.688 | 8.00
8pF/6.3V/NC | CeramicCapacitor,22uF,6.3V,+/-20%,X5R,0603,Samsung | C18 | 0201 | CeramicCapacitor | 1 | C18 | 1 | 已贴装 |  | 0 | 已贴装 | C106227 | 不需要 | 30 | 60 | 0.6000 | 厚膜电阻 0Ω ±1% 50mW | RC0201FR-070RL | 0201 | 20 | 10 | 商城现货 | 0.0064 | 0.256 | 8.00

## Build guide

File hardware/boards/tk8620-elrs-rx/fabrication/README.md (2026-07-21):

# Fabrication Files

This directory contains manufacturing files for this hardware module. Use them
to evaluate PCB prototyping, assembly, production, and test flow.

Manufacturing files should be generated from the matching [`../eda/`](../eda/)
source project. Before production, perform your own DFM, BOM, placement, RF,
power, and regulatory checks.

## Files

- [`gerber_ELRS-RX-MODULE-V11-20260204/`](gerber_ELRS-RX-MODULE-V11-20260204/):
  Gerber layers, NC drill data, aperture data, generation reports, and
  fabrication test-point reports.
- [`BOM表.xls`](BOM表.xls): bill of materials.

Pick-and-place files, separate fabrication and assembly drawings, and
production test notes are not included in this release.

## Notes

- Do not mix these files with files from another hardware module.
- The Gerber headers identify Altium Designer 22.0.2 (36) as the generation
  software. The editable source project is documented for Altium Designer 16.
- If you modify the source project, regenerate all affected manufacturing files.
- Use production releases only after your own manufacturing validation.

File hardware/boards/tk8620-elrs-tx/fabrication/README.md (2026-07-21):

# Fabrication Files

This directory contains manufacturing files for this hardware module. Use them
to evaluate PCB prototyping, assembly, production, and test flow.

Manufacturing files should be generated from the matching [`../eda/`](../eda/)
source project. Before production, perform your own DFM, BOM, placement, RF,
power, and regulatory checks.

## Files

- [`Gerber-ELRS-TX-MODULE-V13-20260610/`](Gerber-ELRS-TX-MODULE-V13-20260610/):
  RS-274X Gerber layers, NC drill and route files, tool lists, and generation
  parameters.
- [`BOM参考.xlsx`](BOM参考.xlsx): bill of materials reference.

Pick-and-place files, separate fabrication and assembly drawings, and
production test notes are not included in this release.

## Notes

- Do not mix these files with files from another hardware module.
- If you modify the source project, regenerate all affected manufacturing files.
- Use production releases only after your own manufacturing validation.

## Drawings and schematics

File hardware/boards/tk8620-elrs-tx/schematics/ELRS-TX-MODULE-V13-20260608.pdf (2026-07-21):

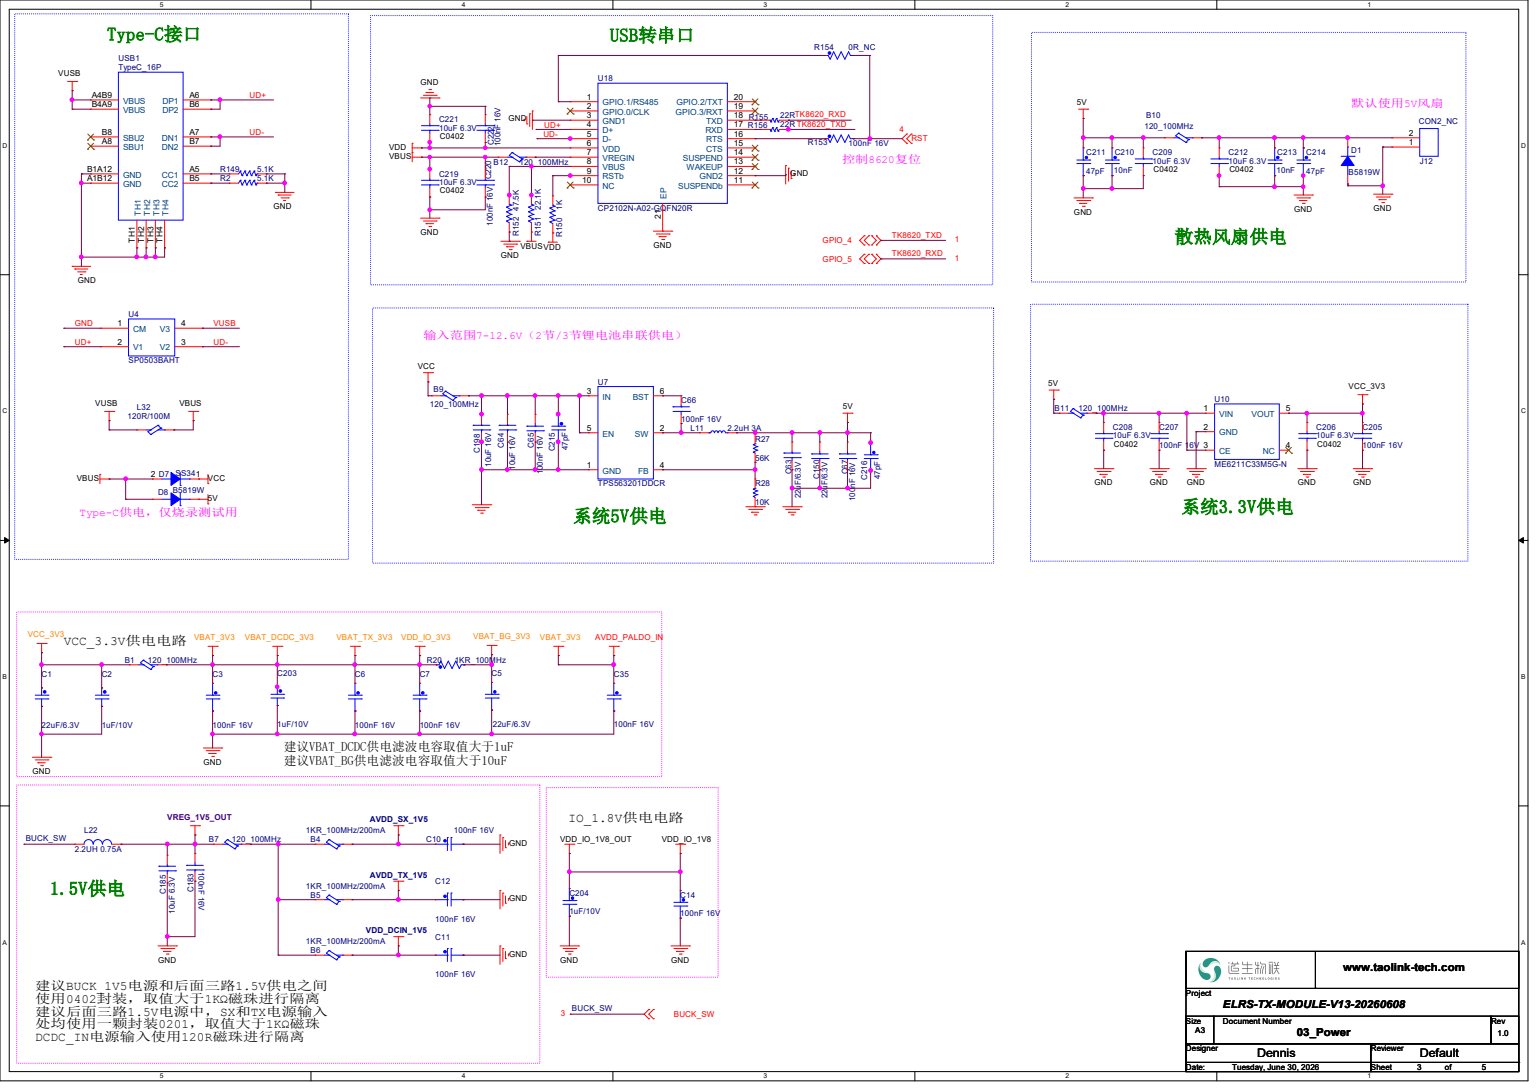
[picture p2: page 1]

www.taolink-tech.com

D

U1

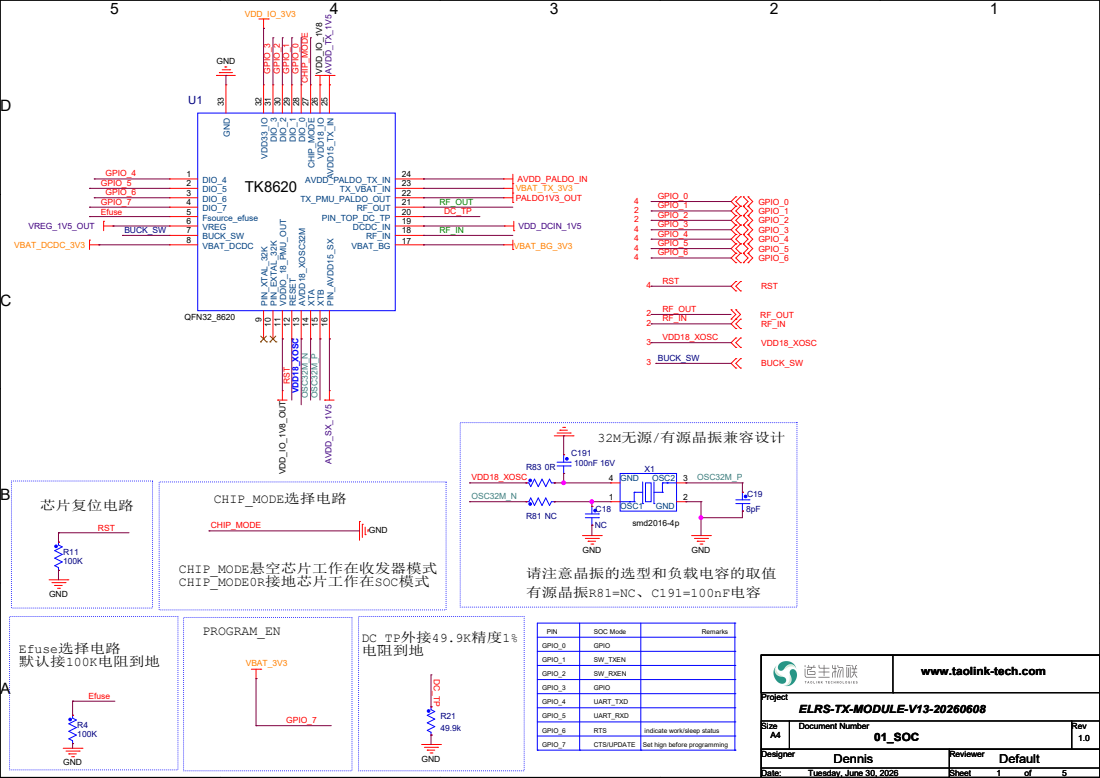
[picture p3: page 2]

PIN | SOC Mode | Remarks
GPIO_0 | GPIO
GPIO_1 | SW_TXEN
GPIO_2 | SW_RXEN
GPIO_3 | GPIO
GPIO_4 | UART_TXD
GPIO_5 | UART_RXD
GPIO_6 | RTS | indicate work/sleep status
GPIO_7 | CTS/UPDATE | Set hign before programming

www.taolink-tech.com

# SOC模式时： R6,R8=0R,R7,R22=NC 此时射频开关由GPIO_1和GPIO_2控制

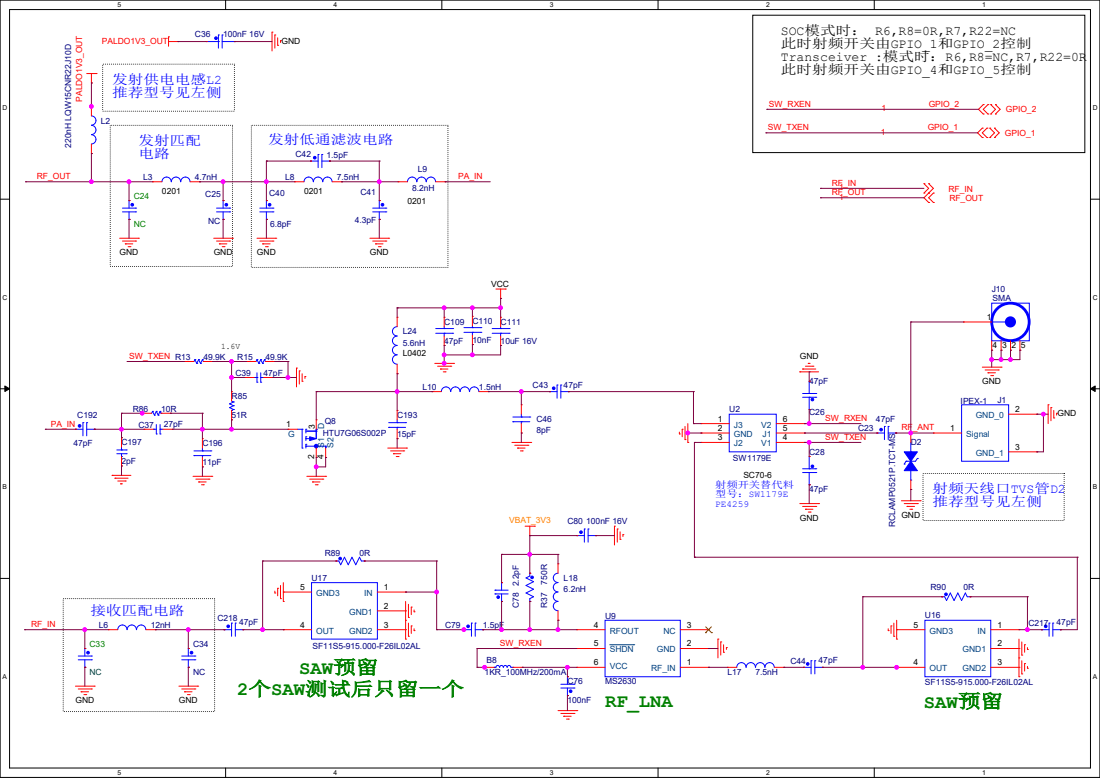
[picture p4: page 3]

## TXD invert/buffer

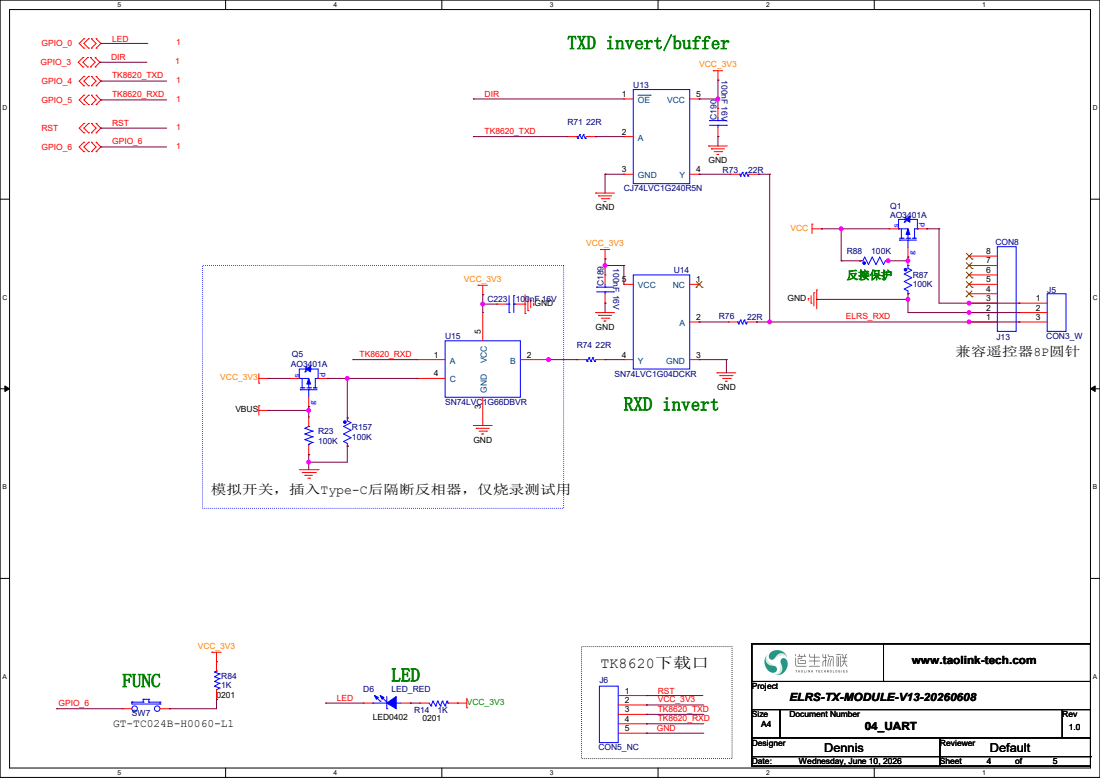
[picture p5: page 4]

模拟开关，插入Type-C后隔断反相器，仅烧录测试用

www.taolink-tech.com

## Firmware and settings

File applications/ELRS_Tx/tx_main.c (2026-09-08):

#include <string.h>

#include "tk86xx_api.h"
#include "serial_port.h"
#include "flash_hal.h"
#include "tk86xx_platform.h"
#include "wdt_hal.h"
#include "eclic_hal.h"
#include "FHSS.h"
#include "device.h"
#include "devHandset.h"
#include "devRadioTx.h"
#include "helpers.h"
#include "common.h"
#include "CRSFHandset.h"
#include "OTA.h"
#include "crc.h"
#include "crsf_protocol.h"
#include "elrs_eeprom.h"
#include "config.h"
#include "options.h"
#include "logging.h"
#include "efuse_hal.h"
#include "devButton.h"
#include "src/lib/LUA/devLUA.h"
#include "lua.h"
#include "msptypes.h"
#include "devLED.h"
#include "stubborn_receiver.h"
#include "CRSF.h"
#include "FIFO.h"
#include "POWERMGNT.h"
#include "dynpower.h"
#include "handset.h"
#include "rx_ota_sender.h"
#include "airport.h"
#include "unified_config.h"

#define BindingSpamAmount 25
// Rate changes have no receiver acknowledgement, so cover low-LQ links with a longer SYNC burst.
#define syncSpamAmount 100
#define syncSpamAmountAfterRateChange 10

#if ELRS_HAS_AIRPORT
static device_affinity_t airport_ui_devices[] = {
    {&ratioTxDevice, 0},
    {&LED_device, 0},
    {&Button_device, 1},
};
#endif
#if !ELRS_AIRPORT
static device_affinity_t rc_ui_devices[] = {
    {&Handset_device, 0},
    {&ratioTxDevice, 0},
    {&LED_device, 0}, // LED_device is defined in devHandset.h
    {&LUA_TxDevice, 0},
    {&Button_device, 1},
};
#endif

ELRS_EEPROM_t eeprom;
TxConfig_t txConfig;
uint8_t MSPDataPackage[5];
static StubbornReceiver_t TelemetryReceiver;
StubbornSender_t MspSender;
// Preserve a changed downlink confirm until an uplink RC packet is actually queued.
static volatile bool TelemetryConfirmPending = false;
static volatile uint32_t LastTLMpacketRecvMillis = 0;
static uint8_t CRSFinBuffer[CRSF_MAX_PACKET_LEN+1];
static uint32_t TLMpacketReported = 0;
static volatile uint32_t syncSpamCounter = 0;
static volatile uint8_t syncSpamCounterAfterRateChange = 0;
static volatile bool ModelUpdatePending = false;
static bool rateCommitActive;
static uint32_t rateCommitAtMs;
static bool commitInProgress = false;
static uint32_t SyncPacketLastSent = 0;
uint32_t rfModeLastChangedMS = 0;
static uint32_t lastLostMillis;
#if !ELRS_AIRPORT
static enum { stbIdle, stbRequested, stbBoosting } syncTelemBoostState = stbIdle;
#endif
static bool DownlinkTlmReceivedThisWindow = false;
static bool TxPayloadPending = false;
static uint32_t TxPayloadQueuedAtMs = 0;
#define TX_PAYLOAD_PENDING_RECOVERY_MS 500U
static bool NextPacketIsMspData = false;
static bool RxOtaModeRequested = false;
static bool RxOtaModeWasActive = false;
static bool txRebootRequested = false;

#if ELRS_HAS_AIRPORT
static AirportFifo_t AirportUartToRf;
static AirportFifo_t AirportRfToUart;

#if ELRS_UNIFIED
RAMCODE_SECTION static void AirportBufferUartByte(uint8_t byte)
{
  (void)AirportFifo_PushBytes(&AirportUartToRf, &byte, 1U);
}
#endif

RAMCODE_SECTION static void AirportUartRxCallback(uint8_t *data, uint8_t len)
{
#if ELRS_UNIFIED
  UnifiedConfig_FilterBytes(data, len, AirportBufferUartByte);
#else
  AirportFifo_PushBytes(&AirportUartToRf, data, len);
#endif
}

static void AirportFlushUartOutput(void)
{
  uint8_t data[AIRPORT_OTA_MAX_PAYLOAD];
  uint16_t count = AirportFifo_PopBytes(&AirportRfToUart, data, sizeof(data));
  if (count != 0U) {
    (void)Tk86xxSerialWrite(data, count);
  }
}
#endif

static void UnifiedStopNormalOperation(void)
{
  UnifiedConfig_SetLoggingEnabled(false);
  DevRadioTx_Stop();
  TxPayloadPending = false;
  connectionState = serialUpdate;
  if (LED_device.event != NULL) (void)LED_device.event();
}

static void UnifiedRequestReboot(void)
{
  txRebootRequested = true;
}

static void SetRFLinkRate(uint8_t index);

static void UpdateLuaDuringRxOta(void)
{
  if (handset.handleInput != NULL)
  {
    (void)handset.handleInput();
  }
  (void)luaHandleUpdateParameter();
  CRSFHandset_FlushOutput();
}

#if SENSI_TEST
#define SENSI_LQ_WINDOW_SIZE 100U

static void PrintSensiStats(SignalQuality_t *signalQuality, bool hasPayload)
{
  static uint8_t rxWindow[SENSI_LQ_WINDOW_SIZE] = {0};
  static uint32_t rxWindowIndex = 0;
  static uint32_t rxWindowCount = 0;
  static uint32_t validRxSlots = 0;
  const uint8_t currentValid = (hasPayload && signalQuality) ? 1U : 0U;

  if (rxWindowCount < SENSI_LQ_WINDOW_SIZE) {
    rxWindowCount++;
  } else if (rxWindow[rxWindowIndex]) {
    validRxSlots--;
  }

  rxWindow[rxWindowIndex] = currentValid;
  validRxSlots += currentValid;
  rxWindowIndex = (rxWindowIndex + 1U) % SENSI_LQ_WINDOW_SIZE;

  uint32_t percent = (validRxSlots * 100U) / rxWindowCount;
  int snr = (hasPayload && signalQuality) ? signalQuality->snr : 0;
  int rssi = (hasPayload && signalQuality) ? signalQuality->rssi : 0;
  tk_printf("%d,%d,%d%%\r\n", snr, rssi, (int)percent);
}
#endif

#define DOWNLINK_LQ_WINDOW_SIZE 25U

typedef struct {
  uint8_t lq;
  uint8_t index;
  uint8_t count;
  uint32_t mask;
  uint32_t bits[(DOWNLINK_LQ_WINDOW_SIZE + 31U) / 32U];
} DownlinkLqCalc_t;

static DownlinkLqCalc_t DownlinkLqCalc = {
  .count = 1,
  .mask = 1U,
};

static bool DownlinkLqCurrentIsSet(void)
{
  return (DownlinkLqCalc.bits[DownlinkLqCalc.index] & DownlinkLqCalc.mask) != 0U;
}

static void DownlinkLqAdd(void)
{
  if (DownlinkLqCurrentIsSet())
    return;

  DownlinkLqCalc.bits[DownlinkLqCalc.index] |= DownlinkLqCalc.mask;
  DownlinkLqCalc.lq++;
}

static uint8_t DownlinkLqGet(void)
{
  return (uint8_t)(((uint32_t)DownlinkLqCalc.lq * 100U) / DownlinkLqCalc.count);
}

static void DownlinkLqInc(void)
{
  DownlinkLqCalc.mask <<= 1;
  if (DownlinkLqCalc.mask == 0U)
  {
    DownlinkLqCalc.mask = 1U;
    DownlinkLqCalc.index++;
  }

  if ((DownlinkLqCalc.index == (DOWNLINK_LQ_WINDOW_SIZE / 32U)) &&
      ((DownlinkLqCalc.mask & (1U << (DOWNLINK_LQ_WINDOW_SIZE % 32U))) != 0U))
  {
    DownlinkLqCalc.index = 0;
    DownlinkLqCalc.mask = 1U;
  }

  if ((DownlinkLqCalc.bits[DownlinkLqCalc.index] & DownlinkLqCalc.mask) != 0U)
  {
    DownlinkLqCalc.bits[DownlinkLqCalc.index] &= ~DownlinkLqCalc.mask;
    DownlinkLqCalc.lq--;
  }

  if (DownlinkLqCalc.count < DOWNLINK_LQ_WINDOW_SIZE)
  {
    DownlinkLqCalc.count++;
  }
}

static bool setupHardwareFromOptions(void)
{
  options_init();
  return true;
}

static void setupBindingFromConfig()
{
    chip_sn_info_t sn_info;

    DBGLN("hasUID: %d", firmwareOptions.hasUID);
    if (firmwareOptions.hasUID) {
        memcpy(UID, firmwareOptions.uid, UID_LEN);
    } else {
        efuse_read_sn_info(&sn_info);
        // DBGLN("chip id:0x%08x", sn_info.chip_id);
#if !SENSI_TEST
        UID[0] = 0;
        UID[1] = 0;
        UID[2] = (uint8_t)(sn_info.chip_id >> 24);
        UID[3] = (uint8_t)(sn_info.chip_id >> 16);
        UID[4] = (uint8_t)(sn_info.chip_id >> 8);
        UID[5] = (uint8_t)(sn_info.chip_id);
#endif
    }

    #ifdef SIM_TUBE
    UID[0] = 0;
    UID[1] = 0;
    UID[2] = 0;
    UID[3] = 0;
    UID[4] = 0;
    UID[5] = 1;
    #endif
    DBGLN("UID=(%02x, %02x, %02x, %02x, %02x, %02x)", UID[0], UID[1], UID[2], UID[3], UID[4], UID[5]);

    OtaUpdateCrcInitFromUid();
}

static void SendUIDOverMSP()
{
    MSPDataPackage[0] = MSP_ELRS_BIND;
    memcpy(&MSPDataPackage[1], &UID[2], 4);
    BindingSendCount = 0;

    MspSender.ResetState();
    MspSender.SetDataToTransmit(MSPDataPackage, 5);
}

static void EnterBindingMode()
{
    if (InBindingMode)
        return;

  // Disable the TX timer and wait for any TX to complete
//   hwTimer::stop();
//   while (busyTransmitting);

    // Queue up sending the Master UID as MSP packets
    SendUIDOverMSP();
    // Binding owns the transmit stream. A preceding configuration/model change
    // may still have SYNC announcements outstanding; none may consume the
    // limited binding packet budget instead of carrying the UID.
    syncSpamCounter = 0;
    syncSpamCounterAfterRateChange = 0;
    rateCommitActive = false;

  // Binding uses a CRCInit=0, 50Hz, and InvertIQ
  OtaCrcInitializer = 0;
  OtaNonce = 0; // Lock the OtaNonce to prevent syncspam packets
  FHSSsetCurrIndex(0);
  InBindingMode = true; // Set binding mode before SetRFLinkRate() for correct IQ

  // Start attempting to bind
  // Lock the RF rate and freq while binding
  SetRFLinkRate(RATE_BINDING);
  ExpressLRS_currTlmDenom = TLMratioEnumToValue(ExpressLRS_currAirRate_Modparams->TLMinterval);

  // Start transmitting again
//   hwTimer::resume();

  DBGLN("Entered binding mode at freq = %d", FHSSgetInitialFreq());
  devicesTriggerEvent();
}

void EnterBindingModeSafely(void)
{
    // TX can always enter binding mode safely as the function handles stopping the transmitter
    EnterBindingMode();
}

void StartRxOtaModeSafely(void)
{
  RxOtaModeRequested = true;
}

void SetSyncSpam()
{
  // Send sync spam if a UI device has requested to and the config has changed
  if (txConfig.IsModified())
  {
    rateCommitActive = false;
    syncSpamCounter = syncSpamAmount;
    syncSpamCounterAfterRateChange = syncSpamAmountAfterRateChange;
  }
}

static void SetRFLinkRate(uint8_t index) // Set speed of RF link
{
  rateCommitActive = false;
    expresslrs_mod_settings_t *const ModParams = get_elrs_airRateConfig(index);
      expresslrs_rf_pref_params_s *const RFperf = get_elrs_RFperfParams(index);
    // Binding always uses invertIQ
    // bool invertIQ = InBindingMode || (UID[5] & 0x01);
    OtaSwitchMode_e newSwitchMode = (OtaSwitchMode_e)txConfig.GetSwitchMode();
    // DBGLN("newSwitchMode = %u", newSwitchMode);

  if ((ModParams == ExpressLRS_currAirRate_Modparams)
    && (RFperf == ExpressLRS_currAirRate_RFperfParams)
    && (OtaSwitchModeCurrent == newSwitchMode))
    return;

    DBGLN("set rate %u", index);
//   uint32_t interval = ModParams->interval;

  // InitialFreq has been set, so lets also reset the FHSS Idx and Nonce.
  FHSSsetCurrIndex(0);
  OtaNonce = 0;

  OtaUpdateSerializers(newSwitchMode, ModParams->PayloadLength);
  MspSender.setMaxPackageIndex(ELRS_MSP_MAX_PACKAGES);
  TelemetryReceiver.setMaxPackageIndex(OtaIsFullRes ? ELRS8_TELEMETRY_MAX_PACKAGES : ELRS4_TELEMETRY_MAX_PACKAGES);

  ExpressLRS_currAirRate_Modparams = ModParams;
  ExpressLRS_currAirRate_RFperfParams = RFperf;
  CRSF_GetLinkStatistics()->crsfLinkStatistics.rf_Mode = ModParams->enum_rate;

//   handset->setPacketInterval(interval * ExpressLRS_currAirRate_Modparams->numOfSends);
  connectionState = disconnected;
  rfModeLastChangedMS = millis();
}

static __attribute__((section(".xip_text"), noinline, noclone))
expresslrs_tlm_ratio_e ConfiguredTlmRatioForRate(uint8_t rateIndex)
{
#if ELRS_HAS_AIRPORT
  if (UnifiedConfig_IsAirport())
    return TLM_RATIO_1_2;
#endif
#if !ELRS_AIRPORT
  expresslrs_tlm_ratio_e configured =
    (expresslrs_tlm_ratio_e)txConfig.GetTlm();
  if (configured == TLM_RATIO_DISARMED)
  {
    const bool armed = (handset.IsArmed != NULL) ? handset.IsArmed() : false;
    if (armed)
      return TLM_RATIO_NO_TLM;
    configured = TLM_RATIO_STD;
  }
  return (configured == TLM_RATIO_STD)
    ? (expresslrs_tlm_ratio_e)get_elrs_airRateConfig(rateIndex)->TLMinterval
    : configured;
#else
  return TLM_RATIO_1_2;
#endif
}

static void ChangeRadioParams()
{
  ModelUpdatePending = false;
  // DBGLN("txConfig.GetRate() = %u", txConfig.GetRate());
  const bool rateChanged =
    txConfig.GetRate() != ExpressLRS_currAirRate_Modparams->index;
  SetRFLinkRate(txConfig.GetRate());
  if (rateChanged)
  {
    ExpressLRS_currTlmDenom =
      TLMratioEnumToValue(ConfiguredTlmRatioForRate(txConfig.GetRate()));
    // Telemetry received on the old PHY schedule cannot prove that the new
    // rate is connected. Clear it before UpdateConnectDisconnectStatus().
    LastTLMpacketRecvMillis = 0;
    // Acquisition at the new rate needs its own retry deadline. Keeping the
    // old link's 10-second deadline can strand a missed initial beacon.
    lastLostMillis = millis() + ExpressLRS_currAirRate_RFperfParams->DisconnectTimeoutMs;
  }
  txLostSignal = true;
  devicesTriggerEvent();
}

static void LinkStatsFromOta(OTA_LinkStats_s * const ls)
{
  DynamicPower_TelemetryUpdate(ls->SNR);
  // DBGLN("LinkStatsFromOta: %d,%d", ls->SNR, ls->uplink_RSSI_1);

  // RSSI received over OTA is a positive -dBm magnitude. Store the CRSF handset
  // value as signed dBm, matching upstream ExpressLRS behavior.
  CRSF_GetLinkStatistics()->crsfLinkStatistics.uplink_RSSI_1 = (uint8_t)(-(int8_t)ls->uplink_RSSI_1);
  CRSF_GetLinkStatistics()->crsfLinkStatistics.uplink_RSSI_2 = (uint8_t)(-(int8_t)ls->uplink_RSSI_2);
  CRSF_GetLinkStatistics()->crsfLinkStatistics.uplink_Link_quality = ls->lq;
#if defined(DEBUG_FREQ_CORRECTION)
  // Don't descale the FreqCorrection value being send in SNR
  CRSF::LinkStatistics.uplink_SNR = snrScaled;
#else
  CRSF_GetLinkStatistics()->crsfLinkStatistics.uplink_SNR = ls->SNR;
#endif
  CRSF_GetLinkStatistics()->crsfLinkStatistics.active_antenna = ls->antenna;
  connectionHasModelMatch = ls->modelMatch;
  // -- downlink_SNR / downlink_RSSI is updated for any packet received, not just Linkstats
  // -- uplink_TX_Power is updated when sending to the handset, so it updates when missing telemetry
  // -- rf_mode is updated when we change rates
  // -- downlink_Link_quality is updated before the LQ period is incremented
  MspSender.ConfirmCurrentPayload(ls->mspConfirm);
}

static bool ProcessTLMpacket(uint8_t *data, uint16_t data_len, SignalQuality_t *signalQuality)
{
  const uint32_t now = millis();
#if !ELRS_AIRPORT
  const bool telemetryConfirmBefore = TelemetryReceiver.GetCurrentConfirm();
#endif
#if SENSI_TEST
  LastTLMpacketRecvMillis = now;
  lastLostMillis = now + 10 * 1000;
  return true;
#endif

  if (data_len < ExpressLRS_currAirRate_Modparams->PayloadLength)
  {
    return false;
  }

  OTA_Packet_s * const otaPktPtr = (OTA_Packet_s * const)data;
  if (!OtaValidatePacketCrc(otaPktPtr))
  {
    // DBGLN("TLM crc error");
    return false;
  }

  if (otaPktPtr->std.type != PACKET_TYPE_TLM)
  {
    DBGLN("TLM type error %d", otaPktPtr->std.type);
    return false;
  }
  // DBGLN("recv TLM packet");
  LastTLMpacketRecvMillis = millis();
  lastLostMillis = now + 10 * 1000;
  DownlinkTlmReceivedThisWindow = true;

  CRSF_GetLinkStatistics()->crsfLinkStatistics.downlink_SNR = signalQuality->snr;
  CRSF_GetLinkStatistics()->crsfLinkStatistics.downlink_RSSI_1 = signalQuality->rssi;
  CRSF_GetLinkStatistics()->downlink_RSSI_2 = 0;

#if ELRS_HAS_AIRPORT
  if (UnifiedConfig_IsAirport()) {
    if (otaPktPtr->full.tlm_dl.containsLinkStats) {
      LinkStatsFromOta(&otaPktPtr->full.tlm_dl.ul_link_stats.stats);
    } else {
      (void)OtaUnpackAirportData(otaPktPtr, &AirportRfToUart);
    }
    return true;
  }
#endif
#if !ELRS_AIRPORT
  // Full res mode
  if (OtaIsFullRes)
  {
    OTA_Packet8_s * const ota8 = (OTA_Packet8_s * const)otaPktPtr;
    uint8_t *telemPtr;
    uint8_t dataLen;
    if (ota8->tlm_dl.containsLinkStats)
    {
      LinkStatsFromOta(&ota8->tlm_dl.ul_link_stats.stats);
      telemPtr = ota8->tlm_dl.ul_link_stats.payload;
      dataLen = sizeof(ota8->tlm_dl.ul_link_stats.payload);
    }
    else
    {
      telemPtr = ota8->tlm_dl.payload;
      dataLen = sizeof(ota8->tlm_dl.payload);
    }
    //DBGLN("pi=%u len=%u", ota8->tlm_dl.packageIndex, dataLen);
    TelemetryReceiver.ReceiveData(ota8->tlm_dl.packageIndex & ELRS8_TELEMETRY_MAX_PACKAGES, telemPtr, dataLen);
  }
  // Std res mode
  else
  {
    switch (otaPktPtr->std.tlm_dl.type)
    {
      case ELRS_TELEMETRY_TYPE_LINK:
        LinkStatsFromOta(&otaPktPtr->std.tlm_dl.ul_link_stats.stats);
        break;

      case ELRS_TELEMETRY_TYPE_DATA:
        TelemetryReceiver.ReceiveData(otaPktPtr->std.tlm_dl.packageIndex & ELRS4_TELEMETRY_MAX_PACKAGES,
          otaPktPtr->std.tlm_dl.payload,
          sizeof(otaPktPtr->std.tlm_dl.payload));
        break;
    }
  }

  if (TelemetryReceiver.GetCurrentConfirm() != telemetryConfirmBefore)
  {
    TelemetryConfirmPending = true;
  }
#endif

  return true;
}

static void RXdoneISR(uint8_t *data, uint16_t data_len, SignalQuality_t *signalQuality)
{
#if SENSI_TEST
  PrintSensiStats(signalQuality, data_len > 0);
  return;
#endif
  // busyTransmitting is required here to prevent accidental rxdone IRQs due to interference triggering RXdoneISR.
  // if (LQCalc.currentIsSet() || busyTransmitting)
  // {
  //   return false; // Already received tlm, do not run ProcessTLMpacket() again.
  // }

  bool packetSuccessful = ProcessTLMpacket(data, data_len, signalQuality);
  UNUSED(packetSuccessful);
#if defined(Regulatory_Domain_EU_CE_2400)
  if (packetSuccessful)
  {
    SetClearChannelAssessmentTime();
  }
#endif

  // return packetSuccessful;
}

static void DownlinkTlmWindowDone(void)
{
  if (DownlinkTlmReceivedThisWindow)
  {
    DownlinkLqAdd();
  }

  CRSF_GetLinkStatistics()->crsfLinkStatistics.downlink_Link_quality = DownlinkLqGet();
  DownlinkLqInc();
  DownlinkTlmReceivedThisWindow = false;
}

static void ClearTxPayloadPending(void)
{
  TxPayloadPending = false;
  TxPayloadQueuedAtMs = 0;
}

static void TXdoneISR(void)
{
//   if (!busyTransmitting)
//   {
//     return; // Already finished transmission and do not call HandleFHSS() a second time, which may hop the frequency!
//   }
  ClearTxPayloadPending();

//   if (connectionState != awaitingModelId)
//   {
//     HandleFHSS();
//     HandlePrepareForTLM();
// #if defined(Regulatory_Domain_EU_CE_2400)
//     if (TelemetryRcvPhase != ttrpPreReceiveGap)
//     {
//       // Start RX for Listen Before Talk early because it takes about 100us
//       // from RX enable to valid instant RSSI values are returned.
//       // If rx was already started by TLM prepare above, this call will let RX
//       // continue as normal.
//       SetClearChannelAssessmentTime();
//     }
// #endif // non-CE
//   }
//   busyTransmitting = false;
}

static expresslrs_tlm_ratio_e UpdateTlmRatioEffective()
{
#if ELRS_HAS_AIRPORT
  if (UnifiedConfig_IsAirport()) {
    ExpressLRS_currTlmDenom = TLMratioEnumToValue(TLM_RATIO_1_2);
    return TLM_RATIO_1_2;
  }
#endif
#if !ELRS_AIRPORT
  expresslrs_tlm_ratio_e ratioConfigured = (expresslrs_tlm_ratio_e)txConfig.GetTlm();
  // DBGLN("ratioConfigured = %u", ratioConfigured);
  // default is suggested rate for TLM_RATIO_STD/TLM_RATIO_DISARMED
  expresslrs_tlm_ratio_e retVal = ExpressLRS_currAirRate_Modparams->TLMinterval;
  bool updateTelemDenom = true;

  // TLM ratio is boosted until there is one complete sync cycle with no BoostRequest
  // if (syncTelemBoostState == stbBoosting)
  // {
  //   syncTelemBoostState = stbIdle;
  // }

  if (syncTelemBoostState == stbRequested)
  {
    syncTelemBoostState = stbBoosting;
    // default to 1:2 telemetry ratio bump for non-wide modes and
    // wide mode configured to 1:4
    retVal = TLM_RATIO_1_2;

    if (!OtaIsFullRes && txConfig.GetSwitchMode() == smWideOr8ch)
    {
      // avoid crossing the wide switch 7-bit to 6-bit boundary
      if (ratioConfigured <= TLM_RATIO_1_8 || ratioConfigured == TLM_RATIO_DISARMED)
      {
        retVal = TLM_RATIO_1_8;
      }
    }
  }
  // If Armed, telemetry is disabled, otherwise use STD
  else if (ratioConfigured == TLM_RATIO_DISARMED)
  {
    const bool armed = (handset.IsArmed != NULL) ? handset.IsArmed() : false;
    if (armed)
    {
      retVal = TLM_RATIO_NO_TLM;
      // Avoid updating ExpressLRS_currTlmDenom until connectionState == disconnected
      if (connectionState == connected)
        updateTelemDenom = false;
    }
  }
  else if (ratioConfigured != TLM_RATIO_STD)
  {
    retVal = ratioConfigured;
  }

  if (updateTelemDenom)
  {
    uint8_t newTlmDenom = TLMratioEnumToValue(retVal);
    // Delay going into disconnected state when the TLM ratio increases
    if (connectionState == connected && ExpressLRS_currTlmDenom > newTlmDenom)
      LastTLMpacketRecvMillis = SyncPacketLastSent;

    if (ExpressLRS_currTlmDenom != newTlmDenom) {
      const uint8_t previousTlmDenom = ExpressLRS_currTlmDenom;
      ExpressLRS_currTlmDenom = newTlmDenom;
      DevRadioTx_RequestTlmRatioChange(previousTlmDenom);
      devicesTriggerEvent();
    }
  }

  return retVal;
#else
  return TLM_RATIO_1_2;
#endif
}

static void GenerateSyncPacketData(OTA_Sync_s * const syncPtr)
{
  const bool airportMode = UnifiedConfig_IsAirport();
  const uint8_t SwitchEncMode = airportMode ? smWideOr8ch : txConfig.GetSwitchMode();
  const uint8_t Index = airportMode ? ExpressLRS_currAirRate_Modparams->index :
    ((syncSpamCounter || rateCommitActive) ? txConfig.GetRate() : ExpressLRS_currAirRate_Modparams->index);

  if (syncSpamCounter)
    --syncSpamCounter;

  if (syncSpamCounterAfterRateChange && Index == ExpressLRS_currAirRate_Modparams->index)
  {
    --syncSpamCounterAfterRateChange;
    if (connectionState == connected) // We are connected again after a rate change.  No need to keep spaming sync.
      syncSpamCounterAfterRateChange = 0;
  }

  SyncPacketLastSent = millis();

  expresslrs_tlm_ratio_e newTlmRatio =
    (Index != ExpressLRS_currAirRate_Modparams->index)
      ? ConfiguredTlmRatioForRate(Index)
      : UpdateTlmRatioEffective();

  syncPtr->fhssIndex = FHSSgetCurrIndex();
  syncPtr->nonce = OtaNonce;
  syncPtr->rateIndex = Index;
  syncPtr->newTlmRatio = newTlmRatio - TLM_RATIO_NO_TLM;
  syncPtr->switchEncMode = SwitchEncMode;
  syncPtr->UID3 = UID[3];
  syncPtr->UID4 = UID[4];
  syncPtr->UID5 = UID[5];

  // For model match, the last byte of the binding ID is XORed with the inverse of the modelId
  if (!InBindingMode && txConfig.GetModelMatch())
  {
    syncPtr->UID5 ^= (uint8_t)((~txConfig.m_modelId) & MODELMATCH_MASK);
  }
}
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
int main(void)
{
    setup();
    while (1) loop();
}

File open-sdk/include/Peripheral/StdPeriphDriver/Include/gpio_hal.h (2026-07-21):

#ifndef __GPIO_HAL_H__
#define __GPIO_HAL_H__

#ifdef __cplusplus
extern "C" {
#endif

typedef struct gpio_s gpio_module_t;

typedef enum {
    GPIO_PIN_A0 = 0, 
    GPIO_PIN_A1,     
    GPIO_PIN_A2,     
    GPIO_PIN_A3,     
    GPIO_PIN_A4,     
    GPIO_PIN_A5,     
    GPIO_PIN_A6,     
    GPIO_PIN_A7,     
    GPIO_PIN_MAX     
} gpio_pin_e;

typedef enum {
    GPIO_PULL_UP = 0, 
    GPIO_PULL_DOWN,   
    GPIO_PULL_NONE,   
    GPIO_PULL_MAX
} gpio_pull_e;

typedef enum {
    GPIO_DIR_IN = 0, 
    GPIO_DIR_OUT,    
    GPIO_DIR_MAX
} gpio_dir_e;

typedef enum iomux_e { // PMUX func
    IOMUX_GPIO           = (0),
    IOMUX_UART0_TXD      = (1),
    IOMUX_UART0_RXD      = (2),
    IOMUX_UART_RTS       = (3),
    IOMUX_UART_CTS       = (4),
    IOMUX_I2C0_SCL       = (5),
    IOMUX_I2C0_SDA       = (6),
    IOMUX_SPI0_CLK       = (7),
    IOMUX_SPI0_RXD       = (8),
    IOMUX_SPI0_TXD       = (9),
    IOMUX_SPI0_CS        = (10),
    IOMUX_DSPI_CLK       = (11),
    IOMUX_DSPI_RXD       = (12),
    IOMUX_DSPI_TXD       = (13),
    IOMUX_DSPI_CS        = (14),
    IOMUX_SIR_IN_OUT     = (15),
    IOMUX_PWM            = (16),
    IOMUX_TS             = (17),
    IOMUX_BB_TEST_BUS    = (18),
    IOMUX_JTAG_OR_CLKOUT = (19),
    IOMUX_CAP_DATA       = (20),
    IOMUX_RESVED0        = (21),
    IOMUX_EXTINT         = (22),
    IOMUX_DIG_CFG        = (23),
    IOMUX_BBU_INTR       = (24),
    IOMUX_AUTO_TRX       = (25),
    IOMUX_MAX
} gpio_af_e;

typedef enum {
    GPIO_PIN_LOW = 0U, 
    GPIO_PIN_HIGH      
} gpio_pin_state_e;

/**
 * @brief  GPIO Configuration Structure definition
 */
typedef struct {
    gpio_pin_e  pin;  
    gpio_dir_e  dir;  
    gpio_pull_e pull; 
} gpio_init_t;

void iomux_set(gpio_pin_e io_idx, gpio_af_e func);

gpio_af_e iomux_get(gpio_pin_e io_idx);

void gpio_init(gpio_module_t *gpiox, gpio_init_t *param);

void gpio_deinit(gpio_module_t *gpiox);

void gpio_pin_write(gpio_module_t *gpiox, gpio_pin_e pin, gpio_pin_state_e state);

gpio_pin_state_e gpio_pin_read(gpio_module_t *gpiox, gpio_pin_e pin);

void gpioa_init(gpio_init_t *param);

void gpioa_deinit(void);

void gpioa_pin_write(gpio_pin_e pin, gpio_pin_state_e state);

gpio_pin_state_e gpioa_pin_read(gpio_pin_e pin);

#ifdef __cplusplus
}
#endif

#endif

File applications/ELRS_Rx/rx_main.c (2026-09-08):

#include <string.h>
#include <stdbool.h>
#include "tk86xx_api.h"
#include "flash_hal.h"
#include "tk86xx_platform.h"
#include "wdt_hal.h"
#include "eclic_hal.h"
#include "crc.h"
#include "FHSS.h"
#include "OTA.h"
#include "common.h"
#include "device.h"
#include "helpers.h"
#include "SerialCRSF.h"
#include "devSerialIO.h"
#include "SerialIO.h"
#include "devRadioRx.h"
#include "elrs_eeprom.h"
#include "config.h"
#include "devLED.h"
#include "devButton.h"
#include "options.h"
#include "msptypes.h"
#include "deferred.h"
#include "telemetry.h"
#include "tk86xx_api.h"
#include "stubborn_sender.h"
#include "stubborn_receiver.h"
#include "CRSF.h"
#include "POWERMGNT.h"
#include "dynpower.h"
#include "src/lib/LUA/devLUA.h"
#include "src/lib/LUA/lua.h"
#include "LowPassFilter.h"
#include "MeanAccumulator.h"
#include "devAnalogVbat.h"
#include "airport.h"
#include "unified_config.h"

#if ELRS_HAS_AIRPORT
static device_affinity_t airport_ui_devices[] = {
    {&ratioRxDevice, 0},
    {&LED_device, 0},
    {&Button_device, 0},
#if defined(USE_ANALOG_VBAT)
    {&AnalogVbat_device, 0},
#endif
};
#endif
#if !ELRS_AIRPORT
static device_affinity_t rc_ui_devices[] = {
    {&Serial0_device, 1},
    {&ratioRxDevice, 0},
    {&LED_device, 0},
    {&Button_device, 0},
#if defined(USE_ANALOG_VBAT)
    {&AnalogVbat_device, 0},
#endif
    {&LUA_device, 0},
};
#endif

SerialIO_t serialIO;
ELRS_EEPROM_t eeprom;
RxConfig_t rxConfig;
bool hardwareConfigured = true;
bool BindingModeRequest = false;
Telemetry_t telemetry;
StubbornSender_t TelemetrySender;
static uint8_t telemetryBurstCount;
static uint8_t telemetryBurstMax;
uint8_t currentTelemetryPayload[CRSF_MAX_PACKET_LEN];
static uint8_t scanIndex;
static uint8_t NextTelemetryType = ELRS_TELEMETRY_TYPE_LINK;
static uint8_t antenna = 0;    // which antenna is currently in use
StubbornReceiver_t MspReceiver;
static uint8_t     MspData[ELRS_MSP_BUFFER];
MeanAccumulator_t SnrMean;
static bool telemBurstValid;
static uint8_t ExpressLRS_nextAirRateIndex;
static int8_t SwitchModePending = 0;
static bool rxRebootRequested;
static bool rateCommitPending;
static uint32_t rateCommitAtMs;
static uint8_t rateCommitTarget;
static uint8_t rateCommitRatio;
static uint8_t rateCommitSwitchMode;
static OTA_Packet_s queuedTelemetryPacket;
static bool queuedTelemetryValid;
static bool telemetryAckArmed;
static bool HandleSendTelemetryResponse(void);
#if ELRS_HAS_AIRPORT
static AirportFifo_t AirportUartToRf;
static AirportFifo_t AirportRfToUart;

#if ELRS_UNIFIED
RAMCODE_SECTION static void AirportBufferUartByte(uint8_t byte)
{
    (void)AirportFifo_PushBytes(&AirportUartToRf, &byte, 1U);
}
#endif

RAMCODE_SECTION static void AirportUartRxCallback(uint8_t *data, uint8_t len)
{
#if ELRS_UNIFIED
    UnifiedConfig_FilterBytes(data, len, AirportBufferUartByte);
#else
    AirportFifo_PushBytes(&AirportUartToRf, data, len);
#endif
}

static void AirportFlushUartOutput(void)
{
    uint8_t data[AIRPORT_OTA_MAX_PAYLOAD];
    uint16_t count = AirportFifo_PopBytes(&AirportRfToUart, data, sizeof(data));
    if (count != 0U) {
        (void)Tk86xxSerialWrite(data, count);
    }
}
#endif

static void UnifiedStopNormalOperation(void)
{
    UnifiedConfig_SetLoggingEnabled(false);
    DevRadioRx_Stop();
    connectionState = serialUpdate;
    if (LED_device.event != NULL) (void)LED_device.event();
}

static void UnifiedRequestReboot(void)
{
    rxRebootRequested = true;
}
LPF_t LPF_UplinkRSSI0 = {
    .Beta = 5,
    .FP_Shift = 5,
    .NeedReset = true,
};

static void SetRFLinkRate(uint8_t index, bool bindMode);

#if SENSI_TEST
#define SENSI_LQ_WINDOW_SIZE 100U

static void PrintSensiStats(SignalQuality_t *signalQuality, bool hasPayload)
{
    static uint8_t rxWindow[SENSI_LQ_WINDOW_SIZE] = {0};
    static uint32_t rxWindowIndex = 0;
    static uint32_t rxWindowCount = 0;
    static uint32_t validRxSlots = 0;
    const uint8_t currentValid = (hasPayload && signalQuality) ? 1U : 0U;

    if (rxWindowCount < SENSI_LQ_WINDOW_SIZE) {
        rxWindowCount++;
    } else if (rxWindow[rxWindowIndex]) {
        validRxSlots--;
    }

    rxWindow[rxWindowIndex] = currentValid;
    validRxSlots += currentValid;
    rxWindowIndex = (rxWindowIndex + 1U) % SENSI_LQ_WINDOW_SIZE;

    uint32_t percent = (validRxSlots * 100U) / rxWindowCount;
    int snr = (hasPayload && signalQuality) ? signalQuality->snr : 0;
    int rssi = (hasPayload && signalQuality) ? signalQuality->rssi : 0;
    tk_printf("%d,%d,%d%%\r\n", snr, rssi, (int)percent);
}
#endif

#define RX_LUA_VERSION_FIELD_ID               2U
// Stubborn transport guarantees delivery; do not occupy it with periodic version pushes.
#if !ELRS_AIRPORT
static bool rxVersionPushQueued;
#endif
void RequestRxReboot(void)
{
    rxRebootRequested = true;
}

#define UPLINK_LQ_HISTORY_SIZE        100U
#define UPLINK_LQ_HISTORY_MIN_SIZE    10U
#define UPLINK_LQ_TARGET_WINDOW_MS  1500U

typedef struct {
    uint8_t windowSize;
    uint8_t lq;
    uint8_t index;
    uint8_t count;
    uint32_t mask;
    uint32_t history[(UPLINK_LQ_HISTORY_SIZE + 31U) / 32U];
} UplinkLqTracker_t;

static UplinkLqTracker_t s_uplinkLqTracker;

static uint8_t UplinkLqTracker_ComputeWindowSize(expresslrs_mod_settings_t const *modParams)
{
    if ((modParams == 0) || (modParams->interval <= 0)) {
        return UPLINK_LQ_HISTORY_SIZE;
    }

    uint32_t rxSlotIntervalUs = (uint32_t)modParams->interval;
    const uint32_t tlmDenom = TLMratioEnumToValue((expresslrs_tlm_ratio_e)modParams->TLMinterval);

    if (tlmDenom > 1U) {
        rxSlotIntervalUs = (((uint32_t)modParams->interval * tlmDenom) + (tlmDenom - 2U)) / (tlmDenom - 1U);
    }

    uint32_t windowSize = ((UPLINK_LQ_TARGET_WINDOW_MS * 1000U) + rxSlotIntervalUs - 1U) / rxSlotIntervalUs;
    if (windowSize < UPLINK_LQ_HISTORY_MIN_SIZE) {
        windowSize = UPLINK_LQ_HISTORY_MIN_SIZE;
    } else if (windowSize > UPLINK_LQ_HISTORY_SIZE) {
        windowSize = UPLINK_LQ_HISTORY_SIZE;
    }

    return (uint8_t)windowSize;
}

static void UplinkLqTracker_Reset(uint8_t windowSize)
{
    memset(&s_uplinkLqTracker, 0, sizeof(s_uplinkLqTracker));
    if ((windowSize == 0U) || (windowSize > UPLINK_LQ_HISTORY_SIZE)) {
        windowSize = UPLINK_LQ_HISTORY_SIZE;
    }
    s_uplinkLqTracker.windowSize = windowSize;
    s_uplinkLqTracker.mask = 1U;
}

static uint8_t UplinkLqTracker_GetLq(void)
{
    if (s_uplinkLqTracker.count == 0U) {
        return 0U;
    }

    return (uint8_t)(((uint32_t)s_uplinkLqTracker.lq * 100U) / s_uplinkLqTracker.count);
}
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

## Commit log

2026-07-21 Add auto-reset UART flasher and hardware layout
    - Rename the BootROM burn tool to tk8620_flasher and package it as a standalone flasher executable.
    - Add CP2102N RTS auto-reset support, local RX flashing, and clearer flashing progress output.
    - Add the hardware directory structure and stop generating firmware-manifest.json build artifacts.
    [tk8620_flasher.py]
2026-07-21 Prepare TK8620 ELRS repository for public release
    - publish TX Cadence and RX Altium hardware design files
    - add schematics, BOMs, Gerbers, and board-specific documentation
    - document module specifications, purchase flow, and customization guidance
    - add CERN-OHL-P-2.0 and complete third-party license texts
    - clarify SDK, bootloader, and bundled tool licensing
    - pin deterministic PyInstaller packaging and rebuild the UART flasher
    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
    [01_SOC.SchDoc, 02_RF.SchDoc, 03_Power.SchDoc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]
2026-07-21 Adjust 915 MHz band and TX product power levels
2026-08-13 Calibrate TX power levels and unify device role macros
    - expose calibrated 50, 100, 250, 500, and 1000 mW TX power options
    - map product power levels to TK8620 drive settings and CRSF values
    - remove unsupported low-power entries and obsolete generic power definitions
    - use explicit TX/RX device role macros during builds
2026-08-20 Add unified RC/AirPort mode support
    - select RC or AirPort at runtime from a CRC-protected Flash record
    - add bidirectional AirPort transport with a separate OTA CRC domain
    - add the interactive application-level configuration tool
    - preserve user parameters by default during local flashing
    - gate UART diagnostics outside RC mode and harden BootROM handshaking
2026-08-28 Sync ExpressLRS 3.6.4 and enhance AirPort configuration
    Port applicable ExpressLRS 3.6.4 maintenance updates. Add persistent selectable AirPort baud rates, an English pair configurator, and RTS auto-reset with manual fallback.
    [rx_main.c, tk8620_configurator.py, tx_main.c]
2026-09-08 Fix rate-switch lockups and link recovery failures
    - Restore connectivity after 50-to-250 Hz changes under Lua polling.
    - Fix binding, Model Match recovery, and incomplete CRSF responses.
    - Prevent telemetry retransmission stalls and stale RC frame delivery.
    [rx_main.c, tx_main.c]
